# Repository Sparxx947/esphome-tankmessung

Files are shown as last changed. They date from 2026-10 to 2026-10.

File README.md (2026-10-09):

🇬🇧 [English version](README.en.md)

# Tankmessung – pneumatische Füllstandsmessung am Öltank

ESP32 + ESPHome misst den Füllstand des Heizöl-Erdtanks über die **vorhandene pneumatische Messleitung**
und meldet Druck, Füllhöhe und Literinhalt an Home Assistant (Gerät „Öltank“).

> Stand: **09.10.2026**. Am Tank eingebaut und in Betrieb: Messleitung frei, dicht, automatische Messung alle 6 h an.
> Füllstand vorläufig über die Lieferbilanz abgeglichen (Peilstab nicht erreichbar); genauer Abgleich bei der nächsten Lieferung.

> **Nachbauen?** Die Werte in diesem Repo gehören zu *diesem* Tank und *diesem* Sensor:
> - Eigene `secrets.yaml` aus [`firmware/secrets.example.yaml`](firmware/secrets.example.yaml) anlegen (WLAN, API-Schlüssel, Passwort des Fallback-Hotspots).
> - Die Tankgeometrie-Substitutions `tank_radius_dm`, `tank_laenge_dm` und `tank_nenn_l` sowie die Öldichte (`oel_mbar_pro_cm`) an den eigenen Tank anpassen.
> - `roh_null` und `roh_pro_mbar` selbst einmessen (siehe [docs/einmessen.md](docs/einmessen.md)) – die Werte in der Firmware gelten nur für genau diesen HX710B-Sensor.

---

## 1. Kurzbeschreibung

| | |
|---|---|
| **Was** | Füllstand des Heizöltanks (Druck in mbar → Füllhöhe in cm → Inhalt in Litern) |
| **Tank** | Stahl-Erdtank, draußen unterirdisch, **7.000 l**, DIN 6608-D, Baujahr 1967, doppelwandig mit Leckanzeiger. Maße laut DIN-6608-Tabelle (heutige Norm): **Ø 1.600 mm × 3.750 mm** – die Normfassung von 1967 ist nicht gegengeprüft. |
| **Wo** | Heizungskeller, an der Wand neben der alten pneumatischen Anzeige (Skala 0–7.000 l mit Zugpumpe). Abgriff: senkrechtes Kupferstück (6 mm) zwischen Abscheiderbecher und alter Anzeige. |
| **Prinzip** | Wie die alte Anzeige („Vor dem Ablesen pumpen“): Eine Mini-Pumpe drückt Luft in die Messleitung, bis sie am Leitungsende ausperlt. Nach dem Abschalten hält ein Rückschlagventil die Luft in der Leitung; der Restdruck entspricht der Ölsäule über dem Leitungsende. Ein Drucksensor (HX710B, 0–40 kPa) misst ihn – auch **während** des Pumpens, mit Überdruck-Abschaltung. Das Leitungsende sitzt über dem Tankboden; die Höhe darunter wird als einstellbare Korrektur addiert. |
| **Physik** | Heizöl EL ρ ≈ 0,84 kg/l → **1 cm Öl ≈ 0,824 mbar**, voller Tank (160 cm) ≈ **132 mbar**, 1 m Öl ≈ 82 mbar. |
| **Volumen** | Liegender Zylinder (Kreisabschnitt), Böden vernachlässigt, auf 7.000 l skaliert (Formel in [docs/einmessen.md](docs/einmessen.md)). |

Die alte Anzeige bleibt angeschlossen, ist aber **defekt** (zeigt drucklos ~800 l, gepumpt knapp 1.900 l bei tatsächlich ~1.500 l). Ergänzend gibt es das Projekt „Heizung über Optolink“
(zweiter ESP32, `heizung-optolink`, .193) für Brennerstunden und Störmeldungen – nicht Teil dieses Repos.

---

## 2. Status (Stand 09.10.2026)

| Bereich | Status | Datum / Hinweis |
|---|---|---|
| Firmware geflasht, in HA, im ESPHome Builder | ✅ fertig | 06.10.2026 ~20:00 |
| Feste IP in der FRITZ!Box (.194) | ✅ fertig | 06.10.2026 |
| MOSFET-Modul: D4184 als untauglich erkannt, durch CQUANZX Dual-MOSFET ersetzt | ✅ fertig | erkannt 06.10., geliefert 07.10. |
| Gehäuse korrigiert (Stützen, SMA-Lage, Laschen, HX710B-Stützen, Innenhöhe 40) | ✅ fertig | 08.10.2026 |
| Gehäuse gedruckt und bestückt, Bestückungsplan gedruckt | ✅ fertig | 08.10.2026 |
| Erster Pumpentest | ✅ läuft (nach Nachklemmen) | 08.10.2026 15:27 |
| **Einmessen am Tisch** (Wassersäule 10 cm) | ✅ fertig | 08.10.2026 16:25, Gegenprobe 16:27 |
| Funktion + Dichtprobe in der Box (60 s) | ✅ dicht (2 von 3 Läufen, ein Abfall ungeklärt) | 08.10.2026 18:07–18:15 |
| Messing-T 6×4×6 | ✅ geliefert, eingebaut | 09.10.2026 |
| **Messleitung frei?** | ✅ frei | 09.10.2026: Druck bleibt beim Pumpen flach auf der Ölsäule (Luft perlt aus) – Freiblasen war nicht nötig |
| Einbau am Tank, erster Lauf, Dichtprobe | ✅ fertig | 09.10.2026 15:44–16:07 (ein Leck an den neuen Anschlüssen gefunden und abgedichtet) |
| Überdruck-Abschaltung + Leitungsende-Korrektur (Firmware) | ✅ geflasht | 09.10.2026 15:52 / 16:06 – Abschaltung **noch nie ausgelöst**, im Ernstfall ungetestet |
| Abgleich Füllstand | ⚠️ vorläufig | Peilstab nicht erreichbar → Lieferbilanz, Korrektur 6,5 cm (Mindestwert); genau bei der nächsten Lieferung |
| Automatische Messung (alle 6 h) | ✅ an | seit 09.10.2026 16:07 |
| HA-Automationen (Warnung, Prognose) | ❌ offen | noch keine angelegt (geprüft 08.10.: keine Automation/kein Skript nutzt das Gerät) |

---

## 3. Stückliste

Quelle: Projektnotizen und Werkstattbuch. Preise zum Bestellzeitpunkt (Oktober 2026, Amazon.de).
Der erste Warenkorb für die Pneumatik (8 Artikel, 54,62 €) wurde am 04.10.2026 bestellt.

### Elektronik

| Teil | Menge | Bezeichnung / Typ | Bezugsquelle, ASIN, Preis | Status |
|---|---|---|---|---|
| Mikrocontroller | 1 | ESP32-WROOM-32U DevKitC V4, USB-C, mit Antennen-Kit (U.FL→SMA-Pigtail + 2,4-GHz-Antenne), Board `esp32dev`, CP2102 | Amazon B0F6567LB5, 13,99 € je Stück (2 bestellt; das zweite steckt im Optolink-Projekt) | ✅ vorhanden, geflasht |
| Drucksensor | 1 (von 3) | Drucksensor-Modul 0–40 kPa mit HX710B (24 bit), Schlauchstutzen für 2,5-mm-Schlauch | Amazon B0B1TZH7RR, 10,99 € (3 Stück) | ✅ vorhanden, eingebaut |
| Luftpumpe | 1 | Mini-Membranpumpe „M20“, DC 3–3,7 V, 80–120 kPa; abgeflachter N20-Motor, 9,95 mm (flache Seiten) × 38 mm, 2 Stutzen stirnseitig, Lötfahnen hinten | Amazon B0GQ3MWP3R, 6,89 € (nur 2 Bewertungen) | ✅ vorhanden, eingebaut |
| MOSFET-Modul | 1 (von 5) | Dual-MOSFET-Triggermodul 15 A / 400 W („XY-MOS“, 2× AOD4184A parallel, **ohne** Optokoppler), Trigger 3,3–20 V, Last 5–36 V, PWM 0–20 kHz, 35 × 17,2 × 14,2 mm | Amazon CQUANZX B07VRCXGFY, 8,49 € (5 Stück) | ✅ geliefert 07.10., eingebaut |
| Freilaufdiode | 1 | Schottky 1N5819 | Diodensortiment BOJACK B07YK3XMQQ, 10,99 € | ✅ geliefert 07.10., eingebaut |
| ~~MOSFET-Modul D4184~~ | – | DollaTek „D4184 MOSFET-Modul“ (PC817-Optokoppler, Gate aus der Lastspannung) – **Fehlkauf, schaltet an 5 V nicht** | Amazon B07HBVTWMY, 5,99 € (5 Stück) | ⚠️ ungenutzt; stornieren oder behalten: Jens entscheidet |
| Kabel | ca. 8 | Dupont-Jumper F2F/M2F (ELEGOO-Set, 20 cm) | vorhanden (gekauft 2023) | ✅ vorhanden |
| Netzteil | 1 | USB-C-Netzteil **≥ 1 A**, 5 V | in den Notizen nicht festgehalten | ❓ ungeklärt |

### Pneumatik

| Teil | Menge | Bezeichnung / Typ | Bezugsquelle, ASIN, Preis | Status |
|---|---|---|---|---|
| T-Stück Messleitung | 1 | Messing-Schlauchtülle-T **6 × 4 × 6 mm** (6 mm Durchgang, 4 mm Abzweig) | Amazon B0GHMXRYNT, 5,99 € (2 Stück) | ✅ eingebaut 09.10. |
| Silikonschlauch 6 mm innen | 1 m | Silikonschlauch 6 mm ID (auf die durchtrennte 6-mm-Kupferleitung) | Amazon B0CYGQD96H, 5,59 € | bestellt 04.10. (Lieferung nicht ausdrücklich notiert) |
| Schlauchschellen | 10 | Edelstahl-Schlauchschellen 6–12 mm (Leryati) | Amazon B0C24792WR, 4,99 € | bestellt 04.10. (Lieferung nicht ausdrücklich notiert) |
| Aquarium-Set | 1 | 48-teilig: 6 m Silikonschlauch 4 mm, Rückschlagventile, T- und L-Verbinder | Amazon B0C2PYBDGJ, 9,99 € | ✅ vorhanden, in der Box verbaut (Rückschlagventil + T) |
| Silikonschlauch 2,5 mm | 1 m | Silikonschlauch 2,5 mm ID × 4 mm AD – passt auf den Sensorstutzen und stramm in den 4-mm-Aquariumschlauch | Amazon B0CXPW74GZ, 4,19 € | bestellt 04.10. (Lieferung nicht ausdrücklich notiert) |
| Messleitung | – | vorhandene Kupferleitung **6 mm außen** (Jens gemessen 6,1 mm) vom Tank in den Keller | Bestand | ✅ frei (09.10.) |

Fallback, falls das Messing-T wieder ausfällt: Steckverbinder-T 6-4-6 POM (B0GLGCTVRH) oder PA (B0CB8V2NXD).
Ungeprüft, ob Steckverbinder auf 6,1-mm-Kupfer dicht und zugfest halten – vor dem Einbau Zugtest + Druckhaltetest.

### Gehäuse und Kleinteile

| Teil | Menge | Bezeichnung / Typ | Bezugsquelle | Status |
|---|---|---|---|---|
| Filament | ca. 1 Box + Deckel | PETG oder PLA (Raumtemperatur, Wandmontage) | Bestand | ✅ Box gedruckt 08.10. (Material nicht notiert) |
| Kabelbinder | 4 | schmal, passend für Schlitze 3,5 × 1,8 mm (2× Pumpe, 1× MOSFET, 1× Ventil) | Bestand | ✅ (Bestand nicht ausdrücklich notiert) |
| Heißkleber | – | HX710B auf seine 2 Stützen | Bestand | ✅ |
| Wandschrauben + Dübel | 4 | für Laschen Ø 4,5 mm (also Schrauben ≤ 4 mm) | – | ❓ nicht in den Notizen |
| Magnete | 0 | – (die 10 × 3-mm-Magnete gehören zum Optolink-Gehäuse) | – | – |
| Widerstände | 0 | Die Schaltung braucht keine (HX710B-Modul und MOSFET-Modul sind fertig bestückt). | – | – |

### Werkzeug / Hilfsmittel

Messschieber, Multimeter, Lötkolben, 3D-Drucker, Glas mit Wasser + Lineal (Einmessen),
Peilstab für den Domschacht (ggf. mit Wasserfindungspaste) – **am 09.10. nicht erreichbar**, Abgleich daher über die Lieferbilanz.

---

## 4. Pinbelegung und Verdrahtung

Schaltplan: [`plaene/tankmessung-schaltplan.pdf`](plaene/tankmessung-schaltplan.pdf)
(Quelle `plaene/tank_plan.py`, Vorschau `plaene/tank_plan.svg`).
Bestückung der Box: [`plaene/tank-bestueckung.pdf`](plaene/tank-bestueckung.pdf) (Quelle `plaene/tank_bestueckung_plan.py`).

> Der Schaltplan-PDF ist auf Stand **08.10.2026** (85 % PWM, eingemessene Werte). Die SVG-Fassung `tank_plan.svg` zeigt noch den Stand 06.10.; die Verdrahtung ist identisch.

| Von | Nach | Hinweis |
|---|---|---|
| HX710B **VCC** | ESP32 **3V3** | **nicht** an 5 V – sonst 5-V-Pegel an GPIO19 |
| HX710B **GND** | ESP32 GND | gemeinsame Masse |
| HX710B **OUT** | **GPIO19** | ESPHome-Plattform `hx711` (`dout_pin`) |
| HX710B **SCK** | **GPIO18** | `clk_pin`, Gain 128 |
| MOSFET **TRIG/PWM** | **GPIO25** | LEDC-PWM 20 kHz |
| MOSFET **GND** (Steuerseite) | ESP32 GND | |
| MOSFET **VIN+** | ESP32 **5V** | 5 V vom DevKit (aus USB, Netzteil ≥ 1 A) |
| MOSFET **VIN−** | ESP32 GND | |
| MOSFET **OUT+** | Pumpe **+ (rot)** | |
| MOSFET **OUT−** | Pumpe **− (schwarz)** | Modul schaltet **Minus** – Pumpe nur an OUT+/OUT−, nie zwischen VIN− und GND |
| 1N5819 | parallel zur Pumpe | **Strich (Kathode) an OUT+**; mit in die Klemmen |
| Antenne | U.FL am Modul → Pigtail → SMA-Buchse in der Vorderwand | Das WROOM-**32U** hat keine Leiterplattenantenne |

Auf der Modul-Unterseite (XY-MOS, laut Foto 08.10.): OUT+ unten, OUT− oben, VIN rechts. Aufdruck auf dem Modul gilt.

**Schlauchführung:**

```
Tankboden ── Kupfer 6 mm ── Messing-T 6×4×6 ──(6-mm-Silikon + Schellen)── alte Anzeige  (dauerhaft DICHT)
                                 │
                            4-mm-Schlauch
                                 │
                       (rechte Wand der Box)
                                 │
                          Aquarium-T 4 mm ──── HX710B-Stutzen (2,5-mm-Silikon)
                                 │
                       Rückschlagventil  (Pfeil zeigt zum T / zur Leitung)
                                 │
                       Pumpe, blasender Stutzen   (Ansaugstutzen OFFEN lassen)
```

---

## 5. Gehäuse

Quelle: [`gehaeuse/tankmessung-gehaeuse.scad`](gehaeuse/tankmessung-gehaeuse.scad) (OpenSCAD, Variable `TEIL = "box" | "deckel" | "alle"`).

| Datei | Wofür | Maße |
|---|---|---|
| `gehaeuse/tank_box.stl` | Box mit ESP-Fach, Stützen, Kabelbinder-Schlitzen, 4 Wandlaschen | außen 114 × 68 × 42 mm (+ Laschen auf 84 mm Breite), innen 110 × 64 × 40 mm |
| `gehaeuse/tank_deckel.stl` | Steckdeckel mit 3-mm-Rand und Ø-3-mm-Loch über der ESP-Status-LED | 114 × 68 × 4,8 mm |
| `gehaeuse/vorschau_tank.png`, `vorschau_tank_oben.png` | Vorschaubilder | – |

**Material/Druck:** PETG oder PLA, 0,2 mm Schicht, **ohne Stützen**, Boden aufs Bett (Beschriftung „TANKMESSUNG“ ist gespiegelt in den Boden eingelassen).

**Aufteilung (Draufsicht, vorne = Wand mit SMA-Buchse):**

| Bereich | Bauteil | Befestigung |
|---|---|---|
| links (x 2–53) | ESP32 DevKitC, USB-C durch die linke Wand | liegt auf **4 Stützen** (17 mm hoch, je ~4,9 mm breit), Stifte + Dupont nach **unten** |
| Trennsteg x ~53 | 6 mm niedriger Anschlag, Kabel gehen drüber | – |
| vorne, x 62 | SMA-Buchse Ø 6,6 mm, 8 mm über dem Boden | Mutter |
| vorne rechts (x 74–109) | MOSFET-Modul, Klemmen zur Mitte | 1 Kabelbinder |
| Mitte (x ~71–89) | HX710B, Stiftleiste nach vorn/unten, Stutzen nach oben | **Heißkleber** auf 2 Stützen (17 mm) unter den Ohren |
| hinten (x 57–95) | Pumpe längs, Lötfahnen links, Stutzen rechts | 2 Kabelbinder |
| rechts | Rückschlagventil, darunter Aquarium-T | 1 Kabelbinder |
| rechte Wand | Schlauch Ø 6,6 mm unten, optionale Kabeldurchführung Ø 5 mm oben | – |
| Rückwand | 8 Lüftungsschlitze | – |

**Lehren aus dem Gehäusebau** (alle vor dem Druck am 08.10. korrigiert):

- **Stiftleisten laufen über die ganze Platinenlänge** (19 × 2,54 mm). Durchgehende Stirn-Auflagen hätten an beiden Enden auf den Stiften gesessen → 4 Einzelstützen, 3,2 mm vom Längsrand, Mitte 12 mm frei (USB-Lötlaschen).
- **SMA-Mutter traf die Stifte**: Bohrung unter der Platine (x 39,5) kollidierte mit der vorderen Stiftleiste → nach x 62 rechts neben das ESP-Fach.
- **Pumpenlaschen lagen quer** zur Pumpe und das MOSFET-Modul ragte 4 mm über die Wand → Laschen nach Jens' Maßen neu gesetzt, Hüllquader-Kollisionsprüfung.
- **HX710B hat die Stiftleiste nach unten** → steht auf Stützen, Innenhöhe 30 → 40 mm (Platz für Stutzen + Schlauchbogen); Dupont ↔ Stützen 1,1/1,4 mm Luft.
- Allgemein: **vor jedem STL-Export Kollisionen prüfen** (Stifte, Muttern, Stecker), Teile vorher mit dem Messschieber messen.
- Die Lochlinie der HX710B-Ohren ist nur aus einem Foto geschätzt – deshalb Heißkleber statt Schrauben.

Ältere Stände liegen lokal als `*.vor-stuetzen-20261008`, `*.vor-laschen-20261008` (per `.gitignore` nicht im Repo).

---

## 6. Firmware

Datei: [`firmware/tankmessung.yaml`](firmware/tankmessung.yaml) – Stand aus dem ESPHome Builder (09.10.2026).
**Die Fassung im ESPHome Builder ist führend**; Änderungen hier nachziehen.

| Einstellung | Wert |
|---|---|
| Gerätename / Hostname | `tankmessung` / `tankmessung.local` |
| Anzeigename in HA | **Öltank** |
| IP | **192.168.178.194** (feste Zuordnung in der FRITZ!Box per MAC) |
| Board / Framework | `esp32dev`, **esp-idf** |
| Logger | INFO |
| API | verschlüsselt (`!secret tank_api_key`), OTA ohne eigenes Passwort |
| Fallback-Hotspot | `Tank-Fallback` + Captive Portal (Passwort `!secret tank_ap_password`) |

**Substitutions:**

| Name | Wert | Bedeutung |
|---|---|---|
| `roh_null` | `-2788747.0` | HX710B-Rohwert bei 0 mbar (eingemessen 08.10., Sensor warm) |
| `roh_pro_mbar` | `70056.0` | Rohwert-Anstieg je mbar |
| `oel_mbar_pro_cm` | `0.824` | Heizöl EL, ρ ≈ 0,84 |
| `tank_radius_dm` | `8.0` | Ø 1,6 m |
| `tank_laenge_dm` | `37.5` | 3,75 m |
| `tank_nenn_l` | `7000` | Skalierung auf Nennvolumen |

**Pumpe:** `ledc` an GPIO25, 20 kHz, `max_power: 85%` (≈ 4,05 V bei 4,77 V VIN; vorher 70 %).
Die Pumpe ist für 3–3,7 V gebaut und hängt an 5 V – deshalb die Begrenzung.
**Sicherung:** Skript `pumpe_sicherung` schaltet die Pumpe nach **60 s** immer ab, auch bei Handbetrieb.

**Messablauf (Skript `messung`):** Pumpe 100 % (= 85 % PWM) für *Spülzeit* (Standard 30 s). **Während des Pumpens** wird der
HX710B alle 0,5 s gelesen; steigt der Druck über die *Überdruck-Grenze* (Standard 150 mbar), geht die Pumpe sofort aus und die
Messung wird verworfen (`binary_sensor.oltank_uberdruck_abbruch` = an). Füllhöhe und Inhalt werden beim Pumpen **nicht** berechnet.
Sonst: Pumpe aus → *Beruhigungszeit* (Standard 10 s) → **15 Einzelwerte** (alle ~0,25 s) → **Median** als Messwert; die 10–90-%-Spanne der 15 Werte landet als *Messstreuung* in HA. Der Sensor wird **nur** in diesem Skript gelesen
(`update_interval: never`). Der höchste Druck beim Pumpen landet in `sensor.oltank_hochstdruck_beim_pumpen`.

**Füllhöhe** = Druck / 0,824 + *Leitungsende über Boden* (Standard 6,5 cm). Die Messleitung endet über dem Tankboden; Öl darunter
sieht die Messung nicht (Herleitung in [docs/einmessen.md](docs/einmessen.md#3-abgleich-am-tank-nach-dem-einbau)).

> Die Überdruck-Abschaltung ist bisher **nie ausgelöst** worden (die Leitung ist frei) – im Ernstfall ungetestet.

### Entitäten in Home Assistant (17, geprüft 09.10.2026)

| Entität | Typ | Zweck |
|---|---|---|
| `button.oltank_messung_starten` | Knopf | eine Messung auslösen |
| `switch.oltank_automatische_messung` | Schalter (Konfig.) | Messung alle 6 h – **ab Werk AUS** (`RESTORE_DEFAULT_OFF`), hier an seit 09.10. |
| `number.oltank_spulzeit_pumpe` | Zahl 5–60 s | Pumpdauer je Messung (30 s) |
| `number.oltank_beruhigungszeit` | Zahl 2–60 s | Wartezeit vor dem Lesen (10 s; für Dichtproben 60 s) |
| `number.oltank_uberdruck_grenze` | Zahl 50–300 mbar | Überdruck-Abschaltung beim Pumpen (150 mbar) |
| `number.oltank_leitungsende_uber_boden` | Zahl 0–30 cm | Korrektur: Höhe des Leitungsendes über dem Tankboden (6,5 cm) |
| `fan.oltank_pumpe` | Lüfter (Diagnose) | Pumpe von Hand, max. 60 s |
| `sensor.oltank_druck_rohwert` | Diagnose | HX710B-Rohwert (für das Einmessen) |
| `sensor.oltank_druck` | mbar | Druck = Ölsäule |
| `sensor.oltank_fullhohe` | cm | Füllhöhe inkl. Korrektur (begrenzt auf 0–160 cm) |
| `sensor.oltank_inhalt` | L | Inhalt, `device_class: volume_storage` |
| `sensor.oltank_hochstdruck_beim_pumpen` | mbar (Diagnose) | höchster Druck während des Pumpens (freie Leitung ≈ Ölsäule) |
| `binary_sensor.oltank_uberdruck_abbruch` | Problem | an = letzte Messung wegen Überdruck abgebrochen (Leitung zu?) |
| `sensor.oltank_messstreuung` | mbar (Diagnose) | 10–90-%-Spanne der 15 Einzelwerte einer Messung (Chip-Rauschen; gemessen 0,04–0,07 mbar) |
| `sensor.oltank_wlan_signal` | dBm | am Tisch −42 dBm, am Tank −50 bis −61 dBm |
| `sensor.oltank_laufzeit` | s | Uptime |
| `button.oltank_neustart` | Knopf (Diagnose) | ESP neu starten |

### Secrets

`firmware/secrets.example.yaml` ist nur eine Vorlage mit Platzhaltern. Die echten Werte (`wifi_ssid`, `wifi_password`,
`tank_api_key`, `tank_ap_password`) stehen **nur im ESPHome Builder** (und lokal außerhalb des Repos, Rechte 600).
`.gitignore` schließt `secrets.yaml` und `secrets.*.yaml` aus. API-Schlüssel neu erzeugen: `openssl rand -base64 32`.

### Flashen

| Weg | Wann | Wie |
|---|---|---|
| **OTA über den ESPHome Builder** (Normalfall) | jede Änderung | YAML im Builder bearbeiten → *Install* → *Wirelessly*. Gerät ist seit 06.10. ~20:05 im Builder online. |
| **Erstflash per USB** | neues Board / kaputte Firmware | `esphome run tankmessung.yaml --no-logs --device /dev/ttyUSB0` mit **echten** Secrets. Port vorher freigeben (`setfacl -m u:$USER:rw /dev/ttyUSB0`, nach jedem Umstecken neu) oder Gruppe `dialout`. |
| **Notweg bei Abbruch** | „No more data to read“ | Dieses Board kam mit 460800 Baud nicht klar: mit `esptool … --baud 115200` die fertige `firmware.factory.bin` schreiben. |

> ⚠️ **Falle:** Nie einen Prüf-Build mit Dummy-Secrets flashen (am 06.10. beim Schwestergerät passiert: falsches
> Hotspot-Passwort, falscher API-Schlüssel). `esphome upload` **übersetzt nicht neu** und spielt blind den letzten Build auf –
> für echte Firmware immer `esphome run` und auf „Successfully compiled“ achten. Danach per API mit dem echten Schlüssel gegenprüfen.

---

## 7. Anleitungen

| Anleitung | Inhalt |
|---|---|
| [docs/aufbau.md](docs/aufbau.md) | Aufbau und Inbetriebnahme auf dem Tisch |
| [docs/einmessen.md](docs/einmessen.md) | **Einmessen/Kalibrieren** mit Wassersäule, Formeln, Peiltabelle, Abgleich am Tank |
| [docs/einbau.md](docs/einbau.md) | Einbau am Tank, Freiblasen der Messleitung, AwSV, erster Lauf, Dichtprobe |
| [docs/fehlersuche.md](docs/fehlersuche.md) | bekannte Fehlerbilder mit Ursache und Lösung |
| [docs/verlauf.md](docs/verlauf.md) | Projektverlauf 04.–09.10.2026 |

Kurzfassung:

1. **Aufbau** nach `plaene/tank-bestueckung.pdf` (Dupont zuerst stecken, dann ESP auf die Stützen).
2. **Inbetriebnahme:** USB-Netzteil an, Gerät in HA online? „Messung starten“ mit offenem Schlauch → Pumpe läuft, bläst.
3. **Einmessen:** Nullpunkt bei offenem Schlauch (Sensor warm, ≥ 5 min nach Einschalten), dann 10 cm Wassersäule = 9,81 mbar →
   `roh_pro_mbar = (roh_10cm − roh_null) / 9,81`. Gegenprobe muss ~10 mbar ergeben.
4. **Einbau:** Abzweig zur alten Anzeige dauerhaft dicht. Ob die Leitung frei ist, zeigt der erste Lauf (Überdruck-Grenze vorher niedrig, z. B. 50 mbar).
5. **Test:** erster Lauf mit 60 s Beruhigungszeit (Dichtprobe), dann Abgleich (Peilstab oder Lieferbilanz), dann Beruhigungszeit 10 s.
6. Erst dann **„Automatische Messung“** einschalten.

---

## 8. Home-Assistant-Anbindung

- Integration: **ESPHome**, Gerät „Öltank“, 17 Entitäten (Tabelle oben).
- **Genauigkeit (09.10.2026 gemessen):** Chip-Rauschen nur 0,04–0,07 mbar (2–4 l), aber **von Lauf zu Lauf bis ~18 l** (vier Messungen in 5 min: 1.528–1.546 l) – vermutlich wie genau die Luft beim Abschalten ausperlt. Deshalb in HA über die letzten 4 Messungen glätten (statistics-Helfer, Mittelwert, max. 30 h) und Warnschwellen daran hängen.
- Läuft die automatische Messung, misst die Box **nach jedem Neustart sofort** einmal (die Pumpe läuft dann kurz an).
- Es gibt **noch keinen `ha/`-Ordner** und keine Automationen/Skripte, die das Gerät nutzen (Suche in HA am 08.10.2026).
- Geplant (aus den Notizen):
  - **Warnung bei niedrigem Stand:** Vorwarnung 1.500 l, dringend 800 l (Push an die Hausbewohner).
  - **Tankprognose** aus dem Verbrauch; Abgleich mit dem Ölverbrauch aus Brennerstunden × Düsendurchsatz (≤ 2,4 l/h) vom Optolink-Projekt.
  - Plausibilität gegen Liefermengen (Referenz: 3.000 l reichten ~14 Monate).
- Hinweis für Automationen: Die Sensoren ändern sich nur nach einer Messung; bei abgeschalteter Automatik bleibt der letzte Wert stehen.

---

## 9. Offene Punkte / nächste Schritte / Termine

| Punkt | Wer | Termin |
|---|---|---|
| **Genauer Abgleich der Leitungsende-Korrektur:** direkt vor und nach der nächsten Lieferung je eine Messung, Liefermenge vom Lieferschein → Korrektur eindeutig | Jens + Claude | nächste Öllieferung |
| Überdruck-Abschaltung im Ernstfall noch ungetestet | – | beobachten |
| Alte Anzeige defekt (drucklos ~800 l) – behalten oder Abzweig dicht verschließen | Jens | – |
| HA: Warnung 1.500 / 800 l, Prognose | Claude | danach |
| D4184-Fehlkauf stornieren oder behalten | Jens | – |
| Grenzwertgeber mit Lochhülse: jährliche Kontrolle durch Fachbetrieb oder Tausch gegen Schlitzhülse (TÜV-Hinweis 2019 + 2024) | Jens | mit der Tankreinigung |
| Nächste AwSV-Prüfung | Jens | 01/2029 (anmelden ab 11/2028) |

---

## 10. Dateiübersicht

```
esphome-tankmessung/
├── README.md                         diese Datei
├── README.en.md                      diese Datei auf Englisch
├── .gitignore                        schließt Secrets, Build-Ordner, Sicherungsstände aus
├── docs/
│   ├── aufbau.md                     Aufbau + Inbetriebnahme am Tisch
│   ├── einmessen.md                  Kalibrierung, Formeln, Peiltabelle
│   ├── einbau.md                     Einbau am Tank, Freiblasen, AwSV, Dichtprobe
│   ├── fehlersuche.md                Fehlerbilder
│   └── verlauf.md                    Chronik
├── firmware/
│   ├── tankmessung.yaml              ESPHome-Konfiguration (Stand Builder 09.10.2026)
│   └── secrets.example.yaml          Vorlage, keine echten Werte
├── gehaeuse/
│   ├── tankmessung-gehaeuse.scad     OpenSCAD-Quelle (Box + Deckel)
│   ├── tank_box.stl                  Box, Innenhöhe 40 (gedruckt 08.10.)
│   ├── tank_deckel.stl               Steckdeckel
│   ├── vorschau_tank.png             Vorschau
│   └── vorschau_tank_oben.png        Vorschau von oben
└── plaene/
    ├── tankmessung-schaltplan.pdf    Schaltplan + Schlauchführung (Stand 08.10.)
    ├── tank_plan.py                  Erzeuger des Schaltplans (matplotlib)
    ├── tank_plan.svg                 Schaltplan als SVG (Stand 06.10.)
    ├── tank-bestueckung.pdf          Bestückungsplan der Box, Maßstab 2:1 (Stand 08.10.)
    └── tank_bestueckung_plan.py      Erzeuger des Bestückungsplans
```

Die Erzeuger-Skripte schreiben noch auf feste Pfade außerhalb des Repos (`~/esphome/…` bzw. ein Scratchpad) – vor erneutem
Aufruf den Ausgabepfad anpassen.

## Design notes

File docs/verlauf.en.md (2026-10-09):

🇩🇪 [Deutsche Version](verlauf.md)

# Project history

| Date | Event |
|---|---|
| 03/04.10.2026 | Viessmann fault D1 (burner fault) – tank empty, nobody noticed. The old pneumatic gauge nevertheless stood at ~800 l, even after pumping → at the time taken as a silted-up line (disproved on 09.10.: ~800 l is the rest position of the defective gauge). |
| 04.10. | Tank data from the TÜV documents: 7,000 l, DIN 6608-D, built 1967, steel, underground, double wall + leak detector, level-limit sensor (Grenzwertgeber); inspections 2019 and 2024 without defects, next 01/2029. Dimensions Ø 1.6 × 3.75 m from the DIN table. |
| 04.10. | Decision for route B (direct pneumatic measurement on the existing line) with ESP32 + HX710B + mini pump; budget variant with brass barb T instead of compression-fitting parts. Basket ordered. YAML and enclosure (inner height 30) prepared. |
| 05.10. | 1,500 l of heating oil delivered, old gauge showed 1,900 l afterwards. Burner runs again after bleeding. Brass T "could not be shipped". |
| 06.10. ~20:00 | Second ESP32 flashed (115200 baud, 460800 aborted), .194, in HA as `Öltank` (oil tank) (12 entities), static IP, online in the ESPHome Builder. |
| 06.10. evening | D4184 MOSFET module identified as unsuitable for 5 V → CQUANZX dual MOSFET + 1N5819 ordered. Schematic redrawn and printed. |
| 07.10. | Delivery: CQUANZX module, diode assortment. |
| 08.10. ~14:30 | Enclosure corrected before printing: ESP standoffs between the pin rows, SMA next to the ESP compartment, tabs according to measured dimensions (MOSFET 35 × 17.2 × 14.2, pump Ø 9.95 × 38), HX710B on 2 standoffs, inner height 40. Brass T reordered. |
| 08.10. ~14:55 | Box printed. |
| 08.10. 15:21–15:35 | First pump test: pump did not run (terminal contact suspected), runs after re-tightening. Zero point drifted. |
| 08.10. ~16:25 | **Calibrated** with 10 cm water column: `roh_null` −2,788,747, `roh_pro_mbar` 70,056, pump 70 → 85 %. The fault was a leak at the gauge branch. OTA via the Builder. |
| 08.10. 16:27 | Cross-check 10.01/10.02 mbar ✔. |
| 08.10. ~17:40 | Assembly plan created and printed. |
| 08.10. 18:07–18:15 | Box assembled: function ✔, leak test 60 s – one drop (unexplained), two runs tight. Settling time back to 10 s. |
| 08.10. ~18:30 | Question of blowing the line clear yourself; AwSV research: more likely subject to the specialist-company requirement, recommendation: specialist company. |
| 09.10. ~15:44 | **Installation at the tank** (brought forward from 10.10.). Box on the wall, Wi-Fi −61 dBm (later −50 dBm). Brass T fitted, branch to the old gauge sealed. Line not blown clear. |
| 09.10. 15:52 | Firmware: pressure is read **while** pumping every 0.5 s, **overpressure cut-off** (adjustable limit, default 150 mbar), max pressure + abort indicator. Reason: previously the pump ran a fixed 30 s – against a blocked line that would have overloaded the sensor. |
| 09.10. 15:53 | **Run 1** (limit 50 mbar for safety): linear rise ~7 mbar/s, from 15:53:43 a **plateau of 30.95 mbar, flat over 25 s of pumping** = air bubbles out → **line clear**, blowing clear not needed. After the pump stopped: drop 30.9 → 21.4 (10 s) → 19.95 mbar (12 s) = **leak at the new connections**. |
| 09.10. 15:59 | Resealed. **Run 2** (settling 60 s): plateau 31.02–31.05 mbar, after 60 s 29.75 mbar → **practically tight** (~1 mbar drops right after the pump stops = flow component, then almost nothing). |
| 09.10. ~16:00 | **Dipstick not reachable.** Delivery balance instead: 1,500 l into an "empty" tank (burner had stopped), ~35 l consumption → at least ~1,465 l. Measured without correction only 36.1 cm ≈ 1,184 l → **the line end sits above the tank bottom**. |
| 09.10. 16:06 | Firmware: adjustable correction **"line end above bottom"**, default **6.5 cm** = minimum (suction pipe assumed 3 cm above the bottom). |
| 09.10. 16:07 | **Automatic measurement switched on.** Check run: plateau 31.10, after 10 s 30.09 mbar → **43.0 cm ≈ 1,516 l**. |
| 09.10. 19:35 | Firmware: **median of 15 readings** + *measurement spread* sensor. Chip noise 0.04–0.07 mbar; run to run up to ~18 l (19:38–19:43: 1,538.6 / 1,545.7 / 1,529.2 / 1,528.0 l) → smoothing in HA over 4 measurements. |
| 09.10. | **Old gauge defective:** ~800 l without pressure, just under 1,900 l when pumped, with ~1,500 l actually in the tank. |

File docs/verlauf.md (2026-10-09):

🇬🇧 [English version](verlauf.en.md)

# Projektverlauf

| Datum | Ereignis |
|---|---|
| 03./04.10.2026 | Viessmann-Störung D1 (Brennerstörung) – Tank leer, niemand hat es bemerkt. Alte pneumatische Anzeige stand trotzdem bei ~800 l, auch nach dem Pumpen → damals für verschlammte Leitung gehalten (am 09.10. widerlegt: ~800 l ist die Ruhestellung des defekten Manometers). |
| 04.10. | Tankdaten aus den TÜV-Unterlagen: 7.000 l, DIN 6608-D, Baujahr 1967, Stahl, unterirdisch, Doppelwand + Leckanzeiger, Grenzwertgeber; Prüfungen 2019 und 2024 ohne Mängel, nächste 01/2029. Maße Ø 1,6 × 3,75 m aus der DIN-Tabelle. |
| 04.10. | Entscheidung für Weg B (direkte pneumatische Messung an der vorhandenen Leitung) mit ESP32 + HX710B + Mini-Pumpe; Spar-Variante mit Messing-Tüllen-T statt Klemmring-Teilen. Warenkorb bestellt. YAML und Gehäuse (Innenhöhe 30) vorbereitet. |
| 05.10. | 1.500 l Heizöl geliefert, alte Anzeige danach 1.900 l. Brenner läuft nach Entlüften wieder. Messing-T „konnte nicht versandt werden“. |
| 06.10. ~20:00 | Zweiter ESP32 geflasht (115200 Baud, 460800 brach ab), .194, in HA als „Öltank“ (12 Entitäten), feste IP, im ESPHome Builder online. |
| 06.10. abends | D4184-MOSFET-Modul als untauglich für 5 V erkannt → CQUANZX Dual-MOSFET + 1N5819 bestellt. Schaltplan neu gezeichnet und gedruckt. |
| 07.10. | Lieferung: CQUANZX-Modul, Diodensortiment. |
| 08.10. ~14:30 | Gehäuse vor dem Druck korrigiert: ESP-Stützen zwischen den Stiftreihen, SMA neben das ESP-Fach, Laschen nach gemessenen Maßen (MOSFET 35 × 17,2 × 14,2, Pumpe Ø 9,95 × 38), HX710B auf 2 Stützen, Innenhöhe 40. Messing-T nachbestellt. |
| 08.10. ~14:55 | Box gedruckt. |
| 08.10. 15:21–15:35 | Erster Pumpentest: Pumpe lief nicht (Klemmkontakt vermutet), nach Nachklemmen läuft sie. Nullpunkt wanderte. |
| 08.10. ~16:25 | **Eingemessen** mit 10 cm Wassersäule: `roh_null` −2.788.747, `roh_pro_mbar` 70.056, Pumpe 70 → 85 %. Störung war ein Leck am Anzeige-Abzweig. OTA über den Builder. |
| 08.10. 16:27 | Gegenprobe 10,01/10,02 mbar ✔. |
| 08.10. ~17:40 | Bestückungsplan erstellt und gedruckt. |
| 08.10. 18:07–18:15 | Box bestückt: Funktion ✔, Dichtprobe 60 s – ein Abfall (ungeklärt), zwei Läufe dicht. Beruhigungszeit zurück auf 10 s. |
| 08.10. ~18:30 | Frage Freiblasen in Eigenregie; AwSV-Recherche: eher fachbetriebspflichtig, Empfehlung Fachbetrieb. |
| 09.10. ~15:44 | **Einbau am Tank** (vorgezogen vom 10.10.). Box an der Wand, WLAN −61 dBm (später −50 dBm). Messing-T eingesetzt, Abzweig zur alten Anzeige dicht. Leitung nicht freigeblasen. |
| 09.10. 15:52 | Firmware: Druck wird **während** des Pumpens alle 0,5 s gelesen, **Überdruck-Abschaltung** (Grenze einstellbar, Standard 150 mbar), Höchstdruck + Abbruch-Melder. Grund: vorher lief die Pumpe stur 30 s – gegen eine verstopfte Leitung hätte das den Sensor überlastet. |
| 09.10. 15:53 | **Lauf 1** (Grenze 50 mbar zur Sicherheit): linearer Anstieg ~7 mbar/s, ab 15:53:43 **Plateau 30,95 mbar flach über 25 s Pumpen** = Luft perlt aus → **Leitung frei**, Freiblasen unnötig. Nach Pumpenstopp Abfall 30,9 → 21,4 (10 s) → 19,95 mbar (12 s) = **Leck an den neuen Anschlüssen**. |
| 09.10. 15:59 | Neu abgedichtet. **Lauf 2** (Beruhigung 60 s): Plateau 31,02–31,05 mbar, nach 60 s 29,75 mbar → **praktisch dicht** (~1 mbar fällt direkt nach Pumpenstopp = Strömungsanteil, danach fast nichts). |
| 09.10. ~16:00 | **Peilstab nicht erreichbar.** Lieferbilanz statt Peilung: 1.500 l in einen „leeren“ Tank (Brenner stand), ~35 l Verbrauch → mindestens ~1.465 l. Gemessen ohne Korrektur nur 36,1 cm ≈ 1.184 l → **das Leitungsende sitzt über dem Tankboden**. |
| 09.10. 16:06 | Firmware: einstellbare Korrektur **„Leitungsende über Boden“**, Standard **6,5 cm** = Mindestwert (Saugrohr 3 cm über Boden angenommen). |
| 09.10. 16:07 | **Automatische Messung eingeschaltet.** Kontrolllauf: Plateau 31,10, nach 10 s 30,09 mbar → **43,0 cm ≈ 1.516 l**. |
| 09.10. 19:35 | Firmware: **Median aus 15 Einzelwerten** + Sensor *Messstreuung*. Chip-Rauschen 0,04–0,07 mbar; Lauf-zu-Lauf aber bis ~18 l (19:38–19:43: 1.538,6 / 1.545,7 / 1.529,2 / 1.528,0 l) → Glättung in HA über 4 Messungen. |
| 09.10. | **Alte Anzeige defekt:** drucklos ~800 l, gepumpt knapp 1.900 l bei tatsächlich ~1.500 l. |

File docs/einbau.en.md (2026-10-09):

🇩🇪 [Deutsche Version](einbau.md)

# Installation at the tank

**Done on 09.10.2026** (Jens, first run together with Claude). Results in [verlauf.en.md](verlauf.en.md).

## Prerequisite: the measuring line must be clear

With the tank empty (fault D1 on 03/04.10.) the old gauge was stuck at ~800 l, even after pumping. After the delivery
of 1,500 l on 05.10. it showed 1,900 l – from this a silted-up line was concluded.
**Disproved on 09.10.:** the line is clear, the gauge is defective (~800 l without pressure). At the bottom of the clear cup (separator in the measuring line below the gauge) there was something dark/reddish –
possibly oil in the measuring line (unconfirmed).

**Sign of a clear line on the first run:** the pressure rises to the oil column and stays flat **while the pump is running**
(09.10.: 30.95 mbar over 25 s). **Above the overpressure limit = line blocked** → since 09.10. the firmware switches the pump
off itself (sensor limit 40 kPa, pump manages 80–120 kPa). For the first run set the limit low (e.g. 50 mbar).

### AwSV: who may do what

> The AwSV (*Verordnung über Anlagen zum Umgang mit wassergefährdenden Stoffen*, German ordinance on facilities handling
> substances hazardous to water) applies to Germany only; other countries have their own rules.

Research 08.10.2026 (not legal advice):

- The installation is **doubly subject to the specialist-company requirement** under § 45 (1) AwSV: underground (no. 1) and heating-oil consumer installation
  level B (no. 4; 7 m³, WGK 2 – water hazard class 2). Subject to the requirement: erecting, cleaning the inside, **repairing**, decommissioning.
- **Making a silted-up line work again** = "restoring" (§ 2 (29)) = repairing → subject to the requirement, unless under
  § 45 (2) (no direct significance for the safety of the installation). **No** source classifies level indicators.
  → Blowing it clear yourself: **unclear, more likely subject to the requirement**.
- **T-piece in the basement:** unclear, lower risk. Sensor/ESP: electrical exemption under TRwS 791 no. 9.1.
- **Replacing the level-limit sensor (Grenzwertgeber):** definitely subject to the requirement.
- Violation: administrative offence (§ 65 no. 25 AwSV / § 103 WHG); according to the NRW FAQ (2019), if executed technically
  correctly, only a formal deficiency. Insurance terms (water damage) not checked.
- **Recommendation:** a specialist company blows the line clear and fits the T at the same time (ideally together with tank cleaning and replacement of the
  level-limit sensor with perforated sleeve). Otherwise a written enquiry to the responsible lower water authority (untere Wasserbehörde).

### If it is blown clear yourself after all (advice from 08.10., decision lies with Jens)

1. **Heating off** and leave it off for 2–3 h afterwards – the end of the line sits in the bottom sludge; stirring it up otherwise leads to a burner fault (filter).
2. **Unscrew** the old gauge and the cup.
3. First use a **bicycle or ball pump** on the 6 mm copper.
4. Compressor only with a **pressure reducer ≤ ~0.5 bar**, in 1–2 s bursts.
5. Someone listens at the manhole/vent: **bubbling = clear**.
6. Afterwards keep an eye on the oil filter at the burner.

## Procedure

1. **Brass T 6×4×6** into the copper measuring line between the cup and the old gauge: cut the vertical copper section
   in the middle, 6 mm silicone hose onto both ends and the barbs, hose clamps. Operating pressure max. ~0.2 bar.
   (Note: silicone swells in mineral oil – fine as long as there is only air/vapour in the line; with oil better use PU/PA hose.)
2. Connect the **branch to the old gauge permanently sealed**. No check valve as a plug – it leaks (test 08.10.).
3. **Box on the wall** (4 tabs, Ø 4.5 mm), 4 mm hose from the T branch into the right wall of the box, USB power supply ≥ 1 A.
4. Wait ≥ 5 min (sensor warm).
5. **First run** with caution: set `number.oltank_uberdruck_grenze` (overpressure limit) to **50 mbar**, `Messung starten`, watch the
   pressure curve in HA (`sensor.oltank_druck` is reported every 0.5 s while pumping). Flat plateau = clear; abort = line blocked or
   high flow resistance. Afterwards set the limit back to 150 mbar.
6. **Leak test:** set `number.oltank_beruhigungszeit` (settling time) to **60 s**, `Messung starten` ("Start measurement"). The pressure after 60 s must match the one after 10 s.
   On the bench: 10.07 → 10.07 mbar and 10.76 / 10.74 mbar = tight. At the tank (09.10.): first run **leaking**
   (30.9 → 21.4 mbar in 10 s), after resealing 31.0 → 29.75 mbar in 60 s = tight.
7. **Comparison**: dipstick in the manhole – or, if it cannot be reached (09.10.), via the **delivery balance**
   (see [einmessen.en.md](einmessen.en.md#3-comparison-at-the-tank-after-installation)) and set `number.oltank_leitungsende_uber_boden`.
8. Settling time **back to 10 s**.
9. Only now **switch on** `switch.oltank_automatische_messung` (automatic measurement; measurement every 6 h).

## Do not touch

- **AFRISO leak detector** above the gauge (tank is double-walled) – the leak lamp was off.
- The old gauge stays connected (read after pumping with the black knob) but reads wrong (gauge defective, ~800 l without pressure).

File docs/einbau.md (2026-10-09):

🇬🇧 [English version](einbau.en.md)

# Einbau am Tank

**Erledigt am 09.10.2026** (Jens, erster Lauf zusammen mit Claude). Ergebnisse in [verlauf.md](verlauf.md).

## Voraussetzung: Die Messleitung muss frei sein

Die alte Anzeige stand bei leerem Tank (Störung D1 am 03./04.10.) fest bei ~800 l, auch nach dem Pumpen. Nach der Lieferung
von 1.500 l am 05.10. zeigte sie 1.900 l – daraus wurde auf eine verschlammte Leitung geschlossen.
**Am 09.10. widerlegt:** Die Leitung ist frei, das Manometer ist defekt (drucklos ~800 l). Am Boden des Klarsichtbechers (Abscheider in der Messleitung unter der Anzeige) lag etwas Dunkles/Rötliches –
möglicherweise Öl in der Messleitung (unbelegt).

**Frei-Kennzeichen beim ersten Lauf:** Der Druck steigt bis zur Ölsäule und bleibt **bei laufender Pumpe** flach stehen
(09.10.: 30,95 mbar über 25 s). **Über der Überdruck-Grenze = Leitung zu** → die Firmware schaltet die Pumpe seit 09.10.
selbst ab (Sensorgrenze 40 kPa, Pumpe schafft 80–120 kPa). Für den ersten Lauf die Grenze niedrig setzen (z. B. 50 mbar).

### AwSV: wer darf was

Recherche 08.10.2026 (keine Rechtsberatung):

- Die Anlage ist **doppelt fachbetriebspflichtig** nach § 45 Abs. 1 AwSV: unterirdisch (Nr. 1) und Heizölverbraucheranlage
  Stufe B (Nr. 4; 7 m³, WGK 2). Pflichtig sind Errichten, innen Reinigen, **Instandsetzen**, Stilllegen.
- **Verschlammte Leitung wieder gängig machen** = „Wiederherstellen“ (§ 2 Abs. 29) = Instandsetzen → pflichtig, außer nach
  § 45 Abs. 2 (keine unmittelbare Bedeutung für die Anlagensicherheit). Für Füllstandsanzeiger ordnet das **keine** Quelle ein.
  → Freiblasen selbst: **unklar, eher pflichtig**.
- **T-Stück im Keller:** unklar, geringeres Risiko. Sensor/ESP: Elektro-Ausnahme nach TRwS 791 Nr. 9.1.
- **Grenzwertgeber-Tausch:** sicher pflichtig.
- Verstoß: Ordnungswidrigkeit (§ 65 Nr. 25 AwSV / § 103 WHG); laut NRW-Zweifelsfragen (2019) bei technisch einwandfreier
  Ausführung nur Ordnungsmangel. Versicherungsbedingungen (Gewässerschaden) ungeprüft.
- **Empfehlung:** Fachbetrieb bläst frei und setzt das T gleich mit (am besten zusammen mit Tankreinigung und Tausch des
  Grenzwertgebers mit Lochhülse). Sonst schriftliche Anfrage an die zuständige untere Wasserbehörde.

### Falls doch selbst freigeblasen wird (Rat vom 08.10., Entscheidung bei Jens)

1. **Heizung aus** und danach 2–3 h aus lassen – das Leitungsende liegt im Bodenschlamm, Aufwirbeln führt sonst zu Brennerstörung (Filter).
2. Alte Anzeige und Becher **abschrauben**.
3. Zuerst mit einer **Fahrrad- oder Ballpumpe** auf das 6-mm-Kupfer.
4. Kompressor nur mit **Druckminderer ≤ ~0,5 bar**, in 1–2-s-Stößen.
5. Jemand horcht am Domschacht/an der Entlüftung: **Blubbern = frei**.
6. Danach den Ölfilter am Brenner beobachten.

## Ablauf

1. **Messing-T 6×4×6** in die Kupfer-Messleitung zwischen Becher und alter Anzeige: senkrechtes Kupferstück mittig
   durchtrennen, 6-mm-Silikonschlauch auf beide Enden und die Tüllen, Schlauchschellen. Betriebsdruck max. ~0,2 bar.
   (Hinweis: Silikon quillt in Mineralöl – in Ordnung, solange nur Luft/Dunst in der Leitung ist; bei Öl lieber PU/PA-Schlauch.)
2. **Abzweig zur alten Anzeige dauerhaft dicht** anschließen. Kein Rückschlagventil als Verschluss – das leckt (Test 08.10.).
3. **Box an die Wand** (4 Laschen, Ø 4,5 mm), 4-mm-Schlauch vom T-Abzweig in die rechte Wand der Box, USB-Netzteil ≥ 1 A.
4. ≥ 5 min warten (Sensor warm).
5. **Erster Lauf** mit Vorsicht: `number.oltank_uberdruck_grenze` auf **50 mbar**, „Messung starten“, Druckverlauf in HA ansehen
   (`sensor.oltank_druck` wird beim Pumpen alle 0,5 s gemeldet). Flaches Plateau = frei; Abbruch = Leitung zu oder hoher
   Strömungswiderstand. Danach Grenze zurück auf 150 mbar.
6. **Dichtprobe:** `number.oltank_beruhigungszeit` auf **60 s**, „Messung starten“. Der Druck nach 60 s muss dem nach 10 s
   entsprechen. Am Tisch: 10,07 → 10,07 mbar und 10,76 / 10,74 mbar = dicht. Am Tank (09.10.): erster Lauf **undicht**
   (30,9 → 21,4 mbar in 10 s), nach Neuabdichten 31,0 → 29,75 mbar in 60 s = dicht.
7. **Abgleich**: Peilstab im Domschacht – oder, wenn er nicht erreichbar ist (09.10.), über die **Lieferbilanz**
   (siehe [einmessen.md](einmessen.md#3-abgleich-am-tank-nach-dem-einbau)) und `number.oltank_leitungsende_uber_boden` setzen.
8. Beruhigungszeit **zurück auf 10 s**.
9. Erst jetzt `switch.oltank_automatische_messung` **einschalten** (Messung alle 6 h).

## Nicht anfassen

- **AFRISO-Leckanzeiger** über der Anzeige (Tank doppelwandig) – Leck-Lampe war aus.
- Die alte Anzeige bleibt angeschlossen (Ablesen nach dem Pumpen mit dem schwarzen Knopf), zeigt aber falsch (Manometer defekt, drucklos ~800 l).

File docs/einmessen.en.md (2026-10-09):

🇩🇪 [Deutsche Version](einmessen.md)

# Calibration

The chain in the firmware:

```
Rohwert (HX710B, 24 bit)  →  Druck p [mbar]  →  Füllhöhe h [cm]  →  Inhalt V [l]
```

(Rohwert = raw value, Druck = pressure, Füllhöhe = fill height, Inhalt = contents.)

## 1. Formulas

| Step | Formula | Constant |
|---|---|---|
| Raw value → pressure | `p = (roh − roh_null) / roh_pro_mbar` | `roh_null = −2.788.747`, `roh_pro_mbar = 70.056` |
| Pressure → fill height | `h = p / 0,824` (clamped to 0 … 160 cm) | Heating oil EL ρ ≈ 0.84 kg/l: 0.84 × 9.81 × 0.01 / 100 ≈ 0.824 mbar/cm |
| Fill height → contents | Circular segment `A = r²·acos((r−h)/r) − (r−h)·√(2rh − h²)` with h in dm, `V = A · L · 7000 / (π·r²·L)` | r = 8 dm, L = 37.5 dm (dished ends neglected, scaled to 7,000 l) |
| Water for calibration | 10 cm water column = **9.81 mbar** | ρ water = 1.0 |

(The constants in the formula column use German number formatting: `−2.788.747` = −2,788,747; `0,824` = 0.824.)

## 2. Calibration on the bench (as done on 08.10.2026)

Required: glass of water, ruler, the box with hose connected, HA entity `sensor.oltank_druck_rohwert` (pressure raw value).

1. **Warm-up:** switch on the device and wait **at least 5 minutes**. Measured: the zero point moved by ~38,500 units in the first
   minutes (≈ 0.55 mbar ≈ 7 mm oil), stable afterwards (16:16 → 16:21 Δ ~300). Noise ~100–300.
2. **Seal the gauge branch:** on the bench, the T had a branch "to the old gauge". A check valve used as a plug leaks
   already at ~10 mbar – that was the actual fault on 08.10. Hold the branch shut or seal it firmly.
3. **Zero point:** hose end open to the air, `Messung starten` ("Start measurement"), note the raw value (2 readings) → `roh_null`.
   - 08.10.: **−2,788,747** (warm).
4. **Slope:** hose end vertically **10 cm below the water surface** (measured from the hose mouth), `Messung starten` ("Start measurement"),
   it must bubble; note the raw value.
   - 08.10.: **−2,101,492**.
5. Calculate:
   ```
   roh_pro_mbar = (roh_10cm − roh_null) / 9,81
                = (−2.101.492 − (−2.788.747)) / 9,81
                = 687.255 / 9,81 ≈ 70.056
   ```
6. Enter the values into the `substitutions` of the YAML in the **ESPHome Builder** → OTA. Mirror the change in the local `firmware/tankmessung.yaml`.
7. **Cross-check:** 10 cm of water again → target 9.81 mbar.
   - 08.10. 16:27: **10.01 / 10.02 mbar** (+2 % ≈ 2 mm immersion depth), fill height 12.1 cm oil equivalent, contents 243 l. ✔

Tolerance: the immersion depth by hand varies by a few millimetres (later runs 10.07 … 10.76 mbar). For the tank,
1 mbar ≈ 1.2 cm of oil; in the lower range that is 20–45 l depending on the height.

## 3. Comparison at the tank (after installation)

The bench calibration only calibrates the sensor. At the tank, further factors come in: position of the line end above the tank bottom,
actual tank dimensions and the oil density. Therefore check against an independent measurement:

1. **Dipstick in the manhole** (possibly with water-finding paste, to detect water/sludge at the bottom).
2. Expectation after the delivery of 05.10. (1,500 l into an "empty" tank, old gauge showed 1,900 l afterwards):

   | Contents | Fill height | Pressure (calculated) |
   |---|---|---|
   | 1,500 l | 42.7 cm | 35.2 mbar |
   | 1,700 l | 46.7 cm | 38.5 mbar |
   | 1,900 l | 50.6 cm | 41.7 mbar |

   Since then the burner has been running again – so the current level is somewhat lower.
   **Resolved on 09.10.:** the 1,900 l were wrong – the old gauge is defective (~800 l without pressure).
3. If the dipstick reading differs:
   - **constant offset in cm** → line end does not sit on the bottom, or sludge; correction via
     `number.oltank_leitungsende_uber_boden` (in the firmware since 09.10., added to the fill height).
   - **proportional deviation** → oil density/tank dimensions; adjust `oel_mbar_pro_cm`.
4. Later, additionally cross-check with every **delivered quantity** (increase in litres before/after the delivery).

### Comparison without a dipstick: delivery balance (09.10.2026)

The dipstick could not be reached. Instead:

- 05.10.: **1,500 l** into an "empty" tank (the burner got no more oil = level at the end of the suction pipe).
- Consumption until 09.10. ~35 l (estimated, ~7 l/day in October) → now **at least ~1,465 l** + the remainder below the suction pipe.
- Measured **without** correction: 30.95–31.1 mbar while pumping, ≈ 30 mbar after 10 s → 36.1 cm ≈ **1,184 l** – less than
  the delivery alone. → The line end sits **above the tank bottom**.

The remainder below the suction pipe stays unknown. Depending on it:

| Suction pipe ends … above bottom | Remainder before delivery | Contents now | Line end above bottom |
|---|---|---|---|
| 3 cm | 30 l | ≈ 1,495 l | **6.5 cm** (set) |
| 5 cm | 65 l | ≈ 1,530 l | 7.2 cm |
| 10 cm | 182 l | ≈ 1,647 l | 9.6 cm |
| 15 cm | 331 l | ≈ 1,796 l | 12.5 cm |
| 20 cm | 505 l | ≈ 1,970 l | 15.8 cm |

The **minimum of 6.5 cm** is set: contents are shown rather too low – the safe side for warnings.
Check run 09.10. 16:07: **43.0 cm ≈ 1,516 l**.

**Exact comparison at the next delivery:** one measurement directly before and one directly after, quantity from the delivery
note. Because the tank is round, each centimetre corresponds to a different number of litres depending on the height – two
heights plus the known litre difference give the correction unambiguously.

## 4. Dipstick table (from the firmware formula)

Calculated with r = 8 dm, L = 37.5 dm, scaled to 7,000 l, 0.824 mbar/cm. The expected raw value applies to the
calibration of 08.10. Pressure and raw value apply **without** the line-end correction; with the correction, a pressure
belongs to the fill height "table height + correction".

| Fill height | Contents | Pressure | Raw value (expected) |
|---|---|---|---|
| 10 cm | 182 l | 8.2 mbar | −2,211,000 |
| 20 cm | 505 l | 16.5 mbar | −1,634,000 |
| 28 cm | 823 l | 23.1 mbar | −1,172,000 |
| 30 cm | 909 l | 24.7 mbar | −1,057,000 |
| 40 cm | 1,369 l | 33.0 mbar | −480,000 |
| 50 cm | 1,869 l | 41.2 mbar | +98,000 |
| 60 cm | 2,398 l | 49.4 mbar | +675,000 |
| 70 cm | 2,944 l | 57.7 mbar | +1,252,000 |
| 80 cm | 3,500 l | 65.9 mbar | +1,829,000 |
| 100 cm | 4,602 l | 82.4 mbar | +2,984,000 |
| 120 cm | 5,631 l | 98.9 mbar | +4,138,000 |
| 140 cm | 6,495 l | 115.4 mbar | +5,293,000 |
| 160 cm | 7,000 l | 131.8 mbar | +6,447,000 |

Warning thresholds (planned): 1,500 l ≈ 42.7 cm, 800 l ≈ 27.5 cm.

> Note (calculated, not verified on the device): the HX710B delivers 24-bit values up to +8,388,607. With this calibration
> that would be reached at around **160 mbar**. A full tank (132 mbar) still fits; values above that are not a fill level,
> but pump pressure in a blocked line.

## 5. Settings after calibration

| Entity | Normal operation | Leak test |
|---|---|---|
| `number.oltank_spulzeit_pumpe` (pump flush time) | 30 s | 30 s |
| `number.oltank_beruhigungszeit` (settling time) | **10 s** | 60 s |
| `number.oltank_uberdruck_grenze` (overpressure limit) | 150 mbar | 150 mbar (first run on a new line: 50 mbar) |
| `number.oltank_leitungsende_uber_boden` (line end above bottom) | 6.5 cm (provisional, see above) | – |
| `switch.oltank_automatische_messung` (automatic measurement) | **on** only after the comparison at the tank (on since 09.10.) | off |

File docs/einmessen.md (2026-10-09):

🇬🇧 [English version](einmessen.en.md)

# Einmessen / Kalibrieren

Die Kette in der Firmware:

```
Rohwert (HX710B, 24 bit)  →  Druck p [mbar]  →  Füllhöhe h [cm]  →  Inhalt V [l]
```

## 1. Formeln

| Schritt | Formel | Konstante |
|---|---|---|
| Rohwert → Druck | `p = (roh − roh_null) / roh_pro_mbar` | `roh_null = −2.788.747`, `roh_pro_mbar = 70.056` |
| Druck → Füllhöhe | `h = p / 0,824` (begrenzt auf 0 … 160 cm) | Heizöl EL ρ ≈ 0,84 kg/l: 0,84 × 9,81 × 0,01 / 100 ≈ 0,824 mbar/cm |
| Füllhöhe → Inhalt | Kreisabschnitt `A = r²·acos((r−h)/r) − (r−h)·√(2rh − h²)` mit h in dm, `V = A · L · 7000 / (π·r²·L)` | r = 8 dm, L = 37,5 dm (Böden vernachlässigt, auf 7.000 l skaliert) |
| Wasser zum Einmessen | 10 cm Wassersäule = **9,81 mbar** | ρ Wasser = 1,0 |

## 2. Einmessen am Tisch (so am 08.10.2026 gemacht)

Benötigt: Glas mit Wasser, Lineal, die Box mit angeschlossenem Schlauch, HA-Entität `sensor.oltank_druck_rohwert`.

1. **Aufwärmen:** Gerät einschalten und **mindestens 5 Minuten** warten. Gemessen: Der Nullpunkt wanderte in den ersten
   Minuten um ~38.500 Einheiten (≈ 0,55 mbar ≈ 7 mm Öl), danach stabil (16:16 → 16:21 Δ ~300). Rauschen ~100–300.
2. **Anzeige-Abzweig dicht machen:** Am Tisch hing am T ein Ast „zur alten Anzeige“. Ein Rückschlagventil als Stopfen leckt
   schon bei ~10 mbar – das war am 08.10. die eigentliche Störung. Ast zuhalten oder fest verschließen.
3. **Nullpunkt:** Schlauchende offen an der Luft, „Messung starten“, Rohwert notieren (2 Lesungen) → `roh_null`.
   - 08.10.: **−2.788.747** (warm).
4. **Steigung:** Schlauchende senkrecht **10 cm unter die Wasseroberfläche** (gemessen ab Schlauchmündung), „Messung starten“,
   es muss perlen; Rohwert notieren.
   - 08.10.: **−2.101.492**.
5. Rechnen:
   ```
   roh_pro_mbar = (roh_10cm − roh_null) / 9,81
                = (−2.101.492 − (−2.788.747)) / 9,81
                = 687.255 / 9,81 ≈ 70.056
   ```
6. Werte in die `substitutions` der YAML im **ESPHome Builder** eintragen → OTA. Lokale `firmware/tankmessung.yaml` nachziehen.
7. **Gegenprobe:** wieder 10 cm Wasser → Soll 9,81 mbar.
   - 08.10. 16:27: **10,01 / 10,02 mbar** (+2 % ≈ 2 mm Eintauchtiefe), Füllhöhe 12,1 cm Öl-Äquivalent, Inhalt 243 l. ✔

Toleranz: Die Eintauchtiefe von Hand schwankt um einige Millimeter (spätere Läufe 10,07 … 10,76 mbar). Für den Tank
bedeutet 1 mbar ≈ 1,2 cm Öl; im unteren Bereich sind das je nach Höhe 20–45 l.

## 3. Abgleich am Tank (nach dem Einbau)

Das Tisch-Einmessen kalibriert nur den Sensor. Am Tank kommen hinzu: Lage des Leitungsendes über dem Tankboden,
tatsächliche Tankmaße und die Öldichte. Deshalb gegen eine unabhängige Messung prüfen:

1. **Peilstab im Domschacht** (ggf. mit Wasserfindungspaste, um Wasser/Schlamm am Boden zu erkennen).
2. Erwartung nach der Lieferung vom 05.10. (1.500 l in einen „leeren“ Tank, alte Anzeige danach 1.900 l):

   | Inhalt | Füllhöhe | Druck (rechnerisch) |
   |---|---|---|
   | 1.500 l | 42,7 cm | 35,2 mbar |
   | 1.700 l | 46,7 cm | 38,5 mbar |
   | 1.900 l | 50,6 cm | 41,7 mbar |

   Seitdem läuft der Brenner wieder – der aktuelle Stand liegt also etwas darunter.
   **Geklärt am 09.10.:** Die 1.900 l waren falsch – das alte Manometer ist defekt (drucklos ~800 l).
3. Weicht die Peilung ab:
   - **konstanter Versatz in cm** → Leitungsende sitzt nicht am Boden bzw. Schlamm; Korrektur über
     `number.oltank_leitungsende_uber_boden` (seit 09.10. in der Firmware, wird zur Füllhöhe addiert).
   - **proportionale Abweichung** → Öldichte/Tankmaße; `oel_mbar_pro_cm` anpassen.
4. Später zusätzlich mit jeder **Liefermenge** gegenprüfen (Zunahme in Litern vor/nach der Lieferung).

### Abgleich ohne Peilstab: Lieferbilanz (09.10.2026)

Der Peilstab war nicht erreichbar. Stattdessen:

- 05.10.: **1.500 l** in einen „leeren“ Tank (der Brenner bekam kein Öl mehr = Spiegel am Ende des Saugrohrs).
- Verbrauch bis 09.10. ~35 l (geschätzt, ~7 l/Tag im Oktober) → jetzt **mindestens ~1.465 l** + Rest unter dem Saugrohr.
- Gemessen **ohne** Korrektur: 30,95–31,1 mbar beim Pumpen, nach 10 s Ruhe ≈ 30 mbar → 36,1 cm ≈ **1.184 l** – weniger als
  allein die Lieferung. → Das Leitungsende sitzt **über dem Tankboden**.

Unbekannt bleibt der Rest unter dem Saugrohr. Abhängig davon:

| Saugrohr endet … über Boden | Rest vor Lieferung | Inhalt jetzt | Leitungsende über Boden |
|---|---|---|---|
| 3 cm | 30 l | ≈ 1.495 l | **6,5 cm** (eingestellt) |
| 5 cm | 65 l | ≈ 1.530 l | 7,2 cm |
| 10 cm | 182 l | ≈ 1.647 l | 9,6 cm |
| 15 cm | 331 l | ≈ 1.796 l | 12,5 cm |
| 20 cm | 505 l | ≈ 1.970 l | 15,8 cm |

Eingestellt ist der **Mindestwert 6,5 cm**: Der Inhalt wird eher zu niedrig angezeigt – für Warnungen die sichere Seite.
Kontrolllauf 09.10. 16:07: **43,0 cm ≈ 1.516 l**.

**Genauer Abgleich bei der nächsten Lieferung:** direkt davor und direkt danach je eine Messung, Liefermenge vom Lieferschein.
Weil der Tank rund ist, entspricht jeder Zentimeter je nach Höhe unterschiedlich vielen Litern – aus zwei Höhen und der
bekannten Literdifferenz ergibt sich die Korrektur eindeutig.

## 4. Peiltabelle (aus der Firmware-Formel)

Rechnerisch mit r = 8 dm, L = 37,5 dm, skaliert auf 7.000 l, 0,824 mbar/cm. Der erwartete Rohwert gilt für die
Einmessung vom 08.10. Druck und Rohwert gelten **ohne** Leitungsende-Korrektur; mit Korrektur gehört ein Druck zur Füllhöhe
„Tabellenhöhe + Korrektur“.

| Füllhöhe | Inhalt | Druck | Rohwert (erwartet) |
|---|---|---|---|
| 10 cm | 182 l | 8,2 mbar | −2.211.000 |
| 20 cm | 505 l | 16,5 mbar | −1.634.000 |
| 28 cm | 823 l | 23,1 mbar | −1.172.000 |
| 30 cm | 909 l | 24,7 mbar | −1.057.000 |
| 40 cm | 1.369 l | 33,0 mbar | −480.000 |
| 50 cm | 1.869 l | 41,2 mbar | +98.000 |
| 60 cm | 2.398 l | 49,4 mbar | +675.000 |
| 70 cm | 2.944 l | 57,7 mbar | +1.252.000 |
| 80 cm | 3.500 l | 65,9 mbar | +1.829.000 |
| 100 cm | 4.602 l | 82,4 mbar | +2.984.000 |
| 120 cm | 5.631 l | 98,9 mbar | +4.138.000 |
| 140 cm | 6.495 l | 115,4 mbar | +5.293.000 |
| 160 cm | 7.000 l | 131,8 mbar | +6.447.000 |

Warnschwellen (geplant): 1.500 l ≈ 42,7 cm, 800 l ≈ 27,5 cm.

> Hinweis (rechnerisch, nicht am Gerät geprüft): Der HX710B liefert 24-bit-Werte bis +8.388.607. Mit dieser Einmessung
> wäre das bei rund **160 mbar** erreicht. Ein voller Tank (132 mbar) passt noch hinein; Werte darüber sind kein Füllstand,
> sondern Pumpendruck in einer verstopften Leitung.

## 5. Einstellungen nach dem Einmessen

| Entität | Normalbetrieb | Dichtprobe |
|---|---|---|
| `number.oltank_spulzeit_pumpe` | 30 s | 30 s |
| `number.oltank_beruhigungszeit` | **10 s** | 60 s |
| `number.oltank_uberdruck_grenze` | 150 mbar | 150 mbar (erster Lauf an neuer Leitung: 50 mbar) |
| `number.oltank_leitungsende_uber_boden` | 6,5 cm (vorläufig, siehe oben) | – |
| `switch.oltank_automatische_messung` | erst nach dem Abgleich am Tank **an** (an seit 09.10.) | aus |

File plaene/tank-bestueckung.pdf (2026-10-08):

# Tankmessung Bestückung der Box (Draufsicht, Deckel ab, Maßstab 2:1)

tank_box.stl Stand 08.10.2026 · Innen 110 × 64 × 40 mm · rote Punktlinien = Kabelbinder durch die Bodenschlitze

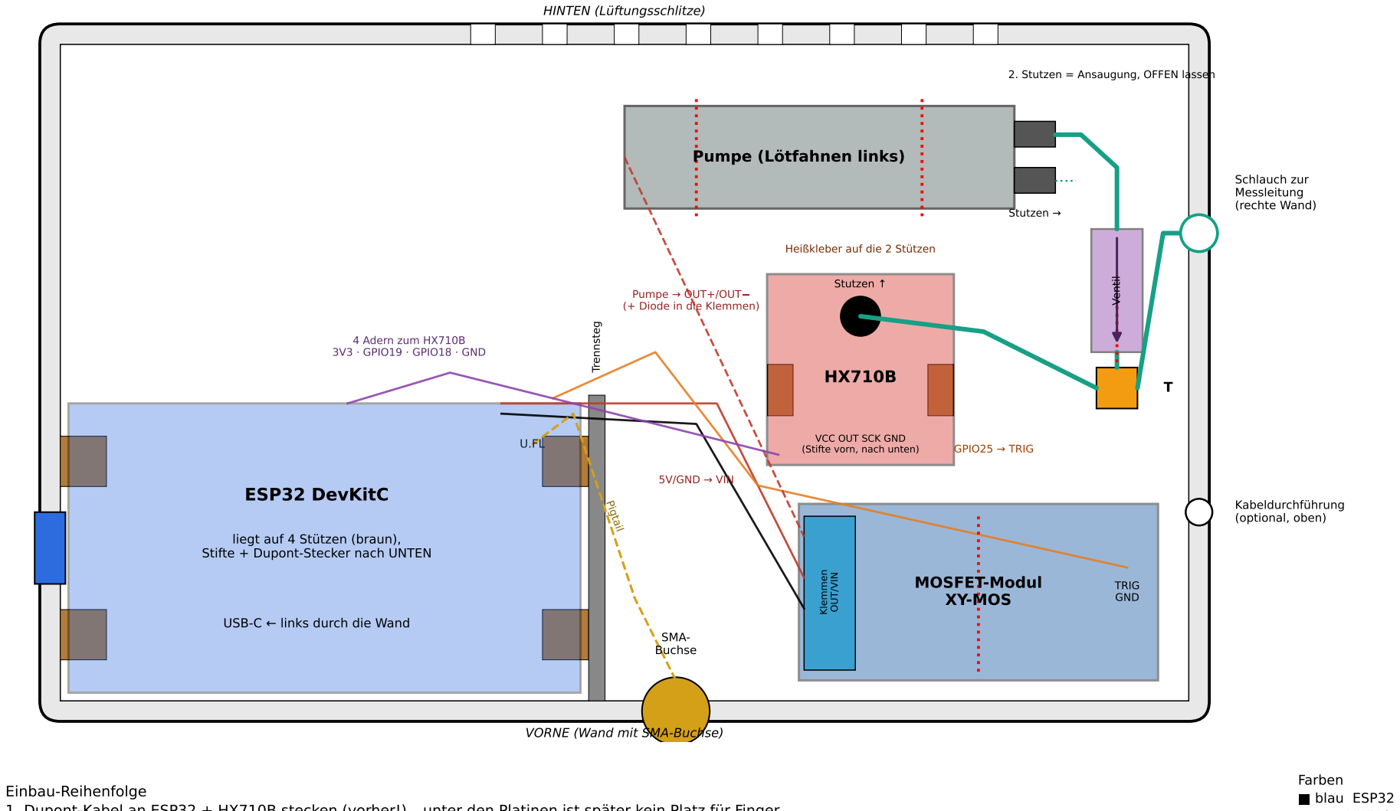
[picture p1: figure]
VORNE (Wand mit SMA-Buchse); HINTEN (Lüftungsschlitze); ESP32 DevKitC; liegt auf 4 Stützen (braun), Stifte + Dupont-Stecker nach UNTEN; USB-C; links durch die Wand; Trennsteg; SMA- Buchse; Pigtail; MOSFET-Modul XY-MOS; Klemmen; OUT/VIN; TRIG GND; VCC OUT SCK GND (Stifte vorn, nach unten); Stutzen; Heißkleber auf die 2 Stützen; Pumpe (Lötfahnen links); Ventil; Schlauch zur Messleitung (rechte Wand); 2. Stutzen = Ansaugung, OFFEN lassen; Kabeldurchführung (optional, oben); 4 Adern zum HX710B 3V3 · GPIO19 · GPIO18 · GND; 5V/GND; VIN; Pumpe; OUT+/OUT; (+ Diode in die Klemmen); GPIO25; TRIG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

1. Dupont-Kabel an ESP32 + HX710B stecken (vorher!) unter den Platinen ist später kein Platz für Finger.
2. ESP32 auf die 4 Stützen legen, USB-C links in die Wandöffnung. Pigtail an U.FL, SMA-Buchse in die vordere Wand rechts neben dem Trennsteg.
3. HX710B mit Heißkleber auf seine 2 Stützen, Stiftleiste nach VORN, Stutzen zeigt nach oben.
4. MOSFET-Modul vorn rechts mit 1 Kabelbinder, Klemmen zur Mitte (links). Diode 1N5819: Strich an OUT+.
5. Pumpe hinten mit 2 Kabelbindern, Stutzen nach rechts. Blasender Stutzen Ventil (Pfeil zum T), Ansaugstutzen offen.
6. Ventil rechts mit 1 Kabelbinder, darunter das T: ein Abgang zum HX710B-Stutzen, einer durch die rechte Wand zur Messleitung.
7. Kabel aufräumen, Deckel drauf. Prüfen: Messung starten am Schlauchende perlt es / bläst es.

rot HX710B
dunkelblau MOSFET
grau Pumpe
lila Rückschlagventil
orange T-Stück
braun Stützen
grün Schläuche
rot Kabelbinder

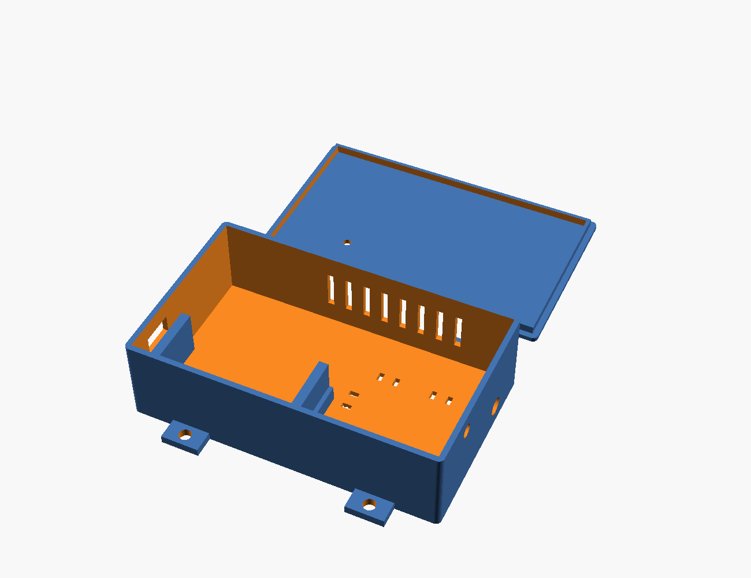
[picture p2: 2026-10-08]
gehaeuse/vorschau_tank.png

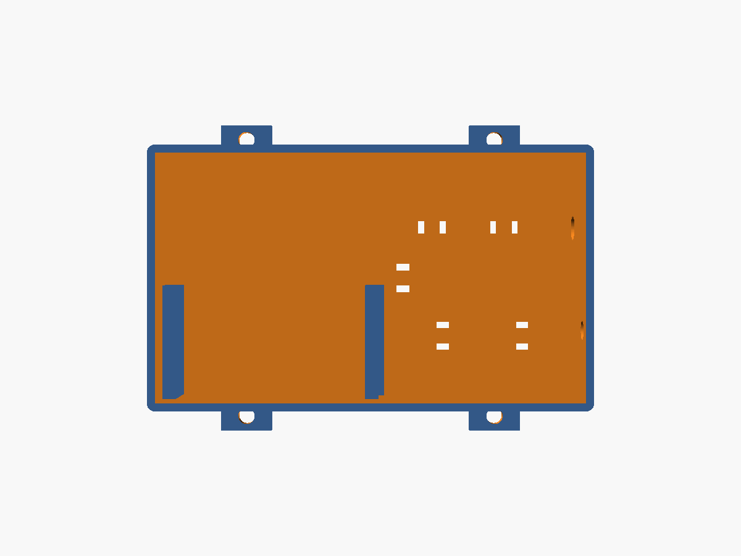
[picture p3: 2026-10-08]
gehaeuse/vorschau_tank_oben.png

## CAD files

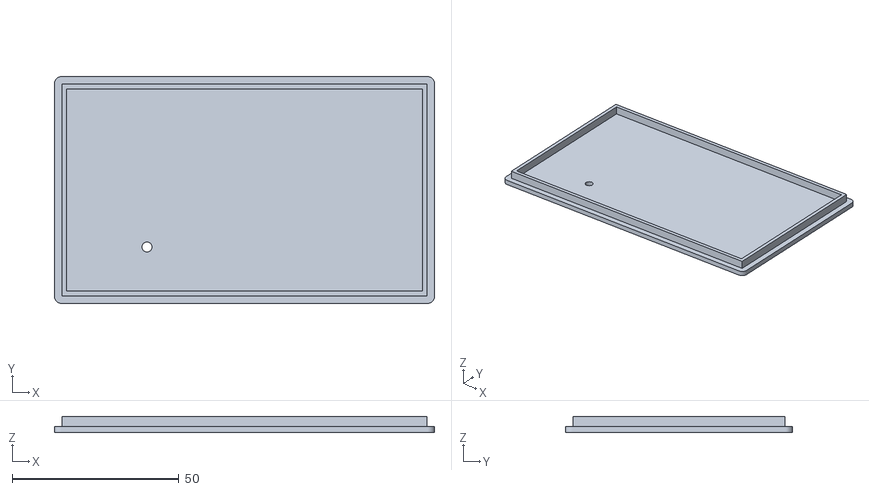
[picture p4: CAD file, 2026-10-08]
gehaeuse/tank_deckel.stl
114.0 x 68.0 x 4.80

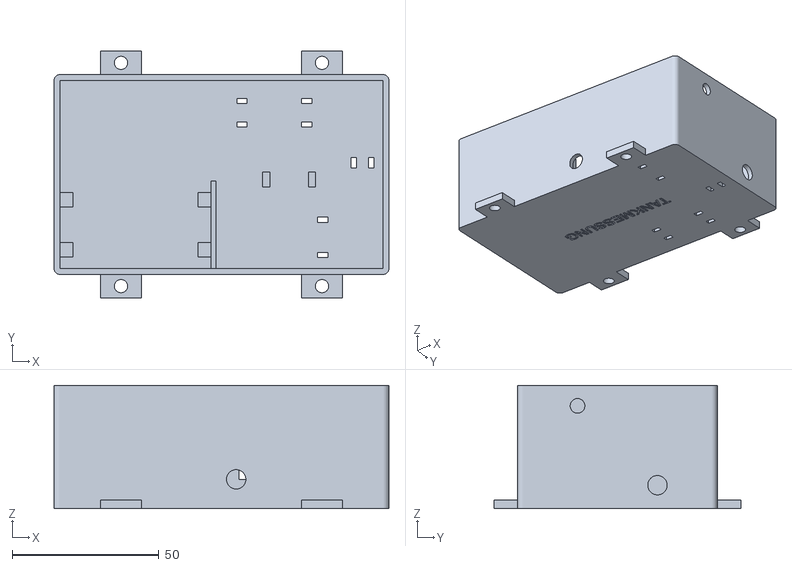
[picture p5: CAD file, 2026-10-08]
gehaeuse/tank_box.stl
114.0 x 84.0 x 42.0

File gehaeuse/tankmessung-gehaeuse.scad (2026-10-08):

// Gehaeuse „Tankmessung“ — pneumatische Oelstandsmessung an der Kupfer-Messleitung
// Inhalt: ESP32-DevKitC (der zweite aus der Bestellung), Drucksensor-Modul 0–40 kPa (HX710B),
//         Mini-Luftpumpe M20 (3 V), Dual-MOSFET-Modul CQUANZX (15 A, ohne Optokoppler; D4184-Modul taugt an 5 V nicht), Rueckschlagventil + T-Verbinder (Aquarium, 4 mm)
// Stand 04.10.2026 — Notiz project_oeltank_fuellstandsensor
//
// Die Masse von Pumpe, Sensor- und MOSFET-Modul sind nicht vermessen. Deshalb werden sie NICHT in
// passgenaue Aufnahmen gesetzt, sondern mit Kabelbindern auf Laschen im Boden gezogen (Schlitze 3,5 x 1,8 mm).
// Nur der ESP32 liegt wie im Heizungsgehaeuse auf Stirn-Auflagen.
//
// Teile: TEIL = "box" | "deckel" | "alle"
// Material: PETG oder PLA (Raumtemperatur, Wandmontage). 0,2 mm Schicht, keine Stuetzen.

TEIL = "alle";
$fn = 48;

// ---------- Innenmasse ----------
iL = 110;          // Laenge
iB = 64;           // Breite
iH = 40;           // Hoehe — 08.10.: 30 → 40, HX710B steht auf 17-mm-Stuetzen (Dupont darunter), Stutzen + Schlauchbogen oben drauf
w  = 2.0;          // Wand
bo = 2.0;          // Boden

// ESP32 (wie im Heizungsgehaeuse)
esp_l = 49.9; esp_b = 28.2; esp_spiel = 0.8;   // 48,24 + 1,6 USB-Ueberstand × 28,15 (Jens gemessen 06.10.)
auflage_h = 17;    // Platz fuer Dupont-Buchsen unter der Platine
auflage_t = 4.5;
usb_b = 12; usb_h = 7; usb_ueber_platte = 1.6;
stift_rand = 3.2;  // Stiftreihen 1,4 mm vom Laengsrand, Kunststoff + Dupont bis ~2,7 mm → Stuetzen bleiben 3,2 mm weg
mitte_frei = 12;   // freie Mitte zwischen den Stuetzen (USB-C-Loetlaschen)
hx_x = 80; hx_y0 = 25;   // HX710B: Mitte in x, Stiftleisten-Kante (vorn) in y
hx_b = 18.14; hx_st = 2.5;   // Breite ueber die Ohren, Stuetzenbreite
sma_x = 62;        // 08.10.: SMA rechts NEBEN dem ESP-Fach (Trennsteg endet bei x 55,1, Mutter ueber Ecken Ø9,2)

// Durchfuehrungen
schlauch_d = 6.6;  // 4-mm-Aquariumschlauch (6 mm aussen) zur Messleitung
kabel_d    = 5;    // optional: Leitung zum Optolink-ESP / Strom
// Kabelbinder-Laschen
kb_l = 3.5; kb_b = 1.8; kb_steg = 6;   // zwei Schlitze im Abstand kb_steg

aL = iL + 2*w; aB = iB + 2*w; aH = bo + iH;
esp_x0 = w;                         // ESP-Fach links (x = 0 … esp_l+2*spiel)
esp_iL = esp_l + 2*esp_spiel;
esp_iB = esp_b + 2*esp_spiel;

module rund_quader(l, b, h, r=2) {
    hull() for (x=[r, l-r], y=[r, b-r]) translate([x,y,0]) cylinder(r=r, h=h);
}

module kabelbinder_lasche(x, y, quer=false, steg=kb_steg) {
    // zwei Schlitze durch den Boden, Kabelbinder von unten durchziehen.
    // quer=false: Schlitze in x versetzt → Binderschlaufe umfasst ein Teil, das LAENGS y liegt.
    // quer=true:  Schlitze in y versetzt → Schlaufe umfasst ein Teil, das LAENGS x liegt.
    for (s=[-steg/2, steg/2])
        translate([x, y, -0.1]) rotate([0,0,quer?90:0])
            translate([s - kb_b/2, -kb_l/2, 0]) cube([kb_b, kb_l, bo+0.2]);
}

module box() {
    platte_z = bo + auflage_h;
    usb_z = platte_z + 1.6 + usb_ueber_platte;
    difference() {
        rund_quader(aL, aB, aH);
        translate([w, w, bo]) cube([iL, iB, iH+1]);

        // USB-C fuer den ESP32 (linke Stirnseite), ESP liegt an der vorderen Wand (y klein)
        translate([-1, w + esp_iB/2 - usb_b/2, usb_z - usb_h/2]) cube([w+2, usb_b, usb_h]);

        // SMA-Antennenbuchse (WROOM-32U braucht die externe Antenne) in der vorderen Wand, rechts neben dem
        // ESP-Fach. 08.10.: vorher unter der Platine bei x 39,5 / z 10 — die Mutter (bis z 14,6) traf dort die
        // Stifte der vorderen Leiste (Spitzen bis z ~10,5, y ~4). Pigtail reicht vom U.FL am Antennenende.
        translate([sma_x, -1, bo + 8]) rotate([-90,0,0]) cylinder(d=6.6, h=w+2);

        // Schlauch zur Messleitung (rechte Stirnseite, unten)
        translate([aL-w-1, aB*0.70, bo+6]) rotate([0,90,0]) cylinder(d=schlauch_d, h=w+2);
        // optionale Kabeldurchfuehrung (rechte Stirnseite, oben)
        translate([aL-w-1, aB*0.30, bo+iH-7]) rotate([0,90,0]) cylinder(d=kabel_d, h=w+2);

        // Lueftung hinten
        for (i=[0:7]) translate([w+40+i*7, aB-w-1, bo+8]) cube([2.4, w+2, 14]);

        // Kabelbinder-Laschen im rechten Bereich (Pumpe, Sensor, MOSFET)
        // 08.10. neu nach Jens' Massen (rechtes Fach innen x 55,1–112, y 2–66). Vorher lag die Pumpe quer zu
        // ihren Bindern und das MOSFET-Modul (35 mm) ragte 4 mm ueber die rechte Wand.
        // Pumpe Ø 9,95 × 38, Stutzen stirnseitig → laengs x, hinten, Stutzen nach rechts (Platz bis Ø 20)
        kabelbinder_lasche(64, 55, true, 8);   // Pumpe x 57–95 (Loetfahnen links, Stutzen ~+4 mm rechts)
        kabelbinder_lasche(86, 55, true, 8);
        // MOSFET CQUANZX 35 × 17,2 × 14,2 → laengs x, vorn rechts (x 74–109, y 4–21), weg von der SMA-Mutter
        kabelbinder_lasche(91.5, 12.6, true, 12);
        // Drucksensor-Modul HX710B: KEINE Binder — Stiftleiste zeigt nach unten (Fotos 08.10.), steht auf zwei Stuetzen (s. u.)
        // Rueckschlagventil / T-Verbinder → rechts, zwischen Pumpenstutzen und Schlauchausgang
        kabelbinder_lasche(105, 38, false, 6);

        // Wandlaschen-Loecher kommen ueber die Laschen (siehe unten)
        // Beschriftung Boden aussen
        translate([aL/2, aB/2, -0.01]) mirror([1,0,0]) linear_extrude(0.5)
            text("TANKMESSUNG", size=5, font="Liberation Sans:style=Bold", halign="center", valign="center");
    }
    // ESP32-Stuetzen: je Stirnseite zwei, ZWISCHEN Stiftleiste und Mitte (wie Optolink-Gehaeuse 07.10.).
    // 08.10.: vorher durchgehende Auflage ueber die ganze Breite → die nach unten zeigenden Stifte
    // (Leisten laufen ueber die ganze Platinenlaenge) waeren an beiden Enden aufgesessen.
    st_b = esp_b/2 - stift_rand - mitte_frei/2;      // Breite je Stuetze (~4,9 mm)
    for (x=[esp_x0, esp_x0 + esp_iL - auflage_t], s=[-1,1])
        translate([x, w + esp_iB/2 + (s>0 ? mitte_frei/2 : -mitte_frei/2 - st_b), bo])
            cube([auflage_t, st_b, auflage_h]);
    // HX710B-Stuetzen unter den beiden Befestigungsohren (Jens 08.10.: Ohrenbreite 18,14, Laenge 18,35, Koerper 13,59,
    // Hoehe ueber Platine bis Stutzen 11,24; Lochlinie ~7,3 mm von der Stiftleisten-Kante, aus Foto geschaetzt).
    // Stiftleiste (VCC OUT SCK GND) liegt 4,9–12,9 mm vom linken Ohrrand → Dupont-Buchsen haben ≥ 1 mm Luft zu den Stuetzen.
    // Befestigung: Heisskleber auf die Stuetzen (Lochabstand nur geschaetzt, daher keine Schraubloecher).
    for (x=[hx_x - hx_b/2, hx_x + hx_b/2 - hx_st])
        translate([x, hx_y0 + 7.3 - 2.5, bo]) cube([hx_st, 5, auflage_h]);
    // Trennsteg als Anschlag fuer die ESP-Platine (nur niedrig, laesst Kabel durch)
    translate([esp_x0 + esp_iL, w, bo]) cube([1.6, esp_iB, 6]);
    // Wandlaschen mit Schraubloch (oben und unten an den Laengsseiten)
    for (x=[aL*0.2, aL*0.8], y=[-8, aB]) translate([x-7, y, 0]) difference() {
        hull() { cube([14, 8, 3]); }
        translate([7, (y<0)?4:4, -1]) cylinder(d=4.5, h=5);
    }
}

module deckel() {
    difference() {
        union() {
            rund_quader(aL, aB, 1.8);
            translate([w+0.25, w+0.25, 1.8]) difference() {
                cube([iL-0.5, iB-0.5, 3]);
                translate([1.4,1.4,-1]) cube([iL-0.5-2.8, iB-0.5-2.8, 5]);
            }
        }
        // Sichtfenster ueber dem ESP fuer die Status-LED (optional)
        translate([w+esp_iL*0.5, w+esp_iB*0.5, -1]) cylinder(d=3, h=5);
    }
}

if (TEIL=="box") box();
if (TEIL=="deckel") deckel();
if (TEIL=="alle") { box(); translate([0, aB+20, 0]) deckel(); }

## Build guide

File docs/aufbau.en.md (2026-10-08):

🇩🇪 [Deutsche Version](aufbau.md)

# Assembly and commissioning (on the bench)

Basis: [`plaene/tank-bestueckung.pdf`](../plaene/tank-bestueckung.pdf) (top view 2:1) and
[`plaene/tankmessung-schaltplan.pdf`](../plaene/tankmessung-schaltplan.pdf). Pin assignment: [README, section 4](../README.en.md#4-pin-assignment-and-wiring).

## 1. Preparation

1. Print box and lid (`gehaeuse/tank_box.stl`, `tank_deckel.stl`; PETG or PLA, 0.2 mm, no supports).
2. Pump: solder the red and black wires to the solder tabs (red = +).
3. Have the flyback diode 1N5819 ready – it goes **into the OUT terminals** of the MOSFET module together with the wires, stripe (cathode) to OUT+.
4. Flash the firmware beforehand (see README, section 6) – once installed, the USB port is still reachable, but tight.

## 2. Assembly (order according to the assembly plan)

1. **Dupont cables first** onto the ESP32 and HX710B – later there is no room for fingers under the boards.
2. Place the **ESP32** on the 4 standoffs, USB-C on the left into the wall opening. Pigtail onto U.FL, SMA socket into the front wall to the right of the divider.
3. **HX710B** with hot glue onto its 2 standoffs, pin header to the **front**, hose barb pointing **up**.
4. **MOSFET module** front right with 1 cable tie, terminals towards the middle. Diode 1N5819: stripe to OUT+.
5. **Pump** at the back with 2 cable ties, ports to the right. Outlet port → check valve (arrow towards the T), leave the **inlet port open**.
6. **Check valve** on the right with 1 cable tie, aquarium T below it: one outlet to the HX710B barb (2.5 mm silicone), one through the right wall to the measuring line.
7. Tidy up the cables, push on the lid.

## 3. Commissioning

| Step | Expectation | If not |
|---|---|---|
| Plug in the USB power supply (≥ 1 A) | Device `Öltank` (oil tank) online in HA, `sensor.oltank_wlan_signal` (Wi-Fi signal) has a value | Fallback hotspot `Tank-Fallback` → captive portal |
| Wait ≥ 5 min | Sensor warm (zero point drifts ~0.5 mbar in the first minutes) | – |
| Hose end open, `button.oltank_messung_starten` (start measurement) | Pump audibly runs for 30 s, air blows out of the hose end; afterwards `sensor.oltank_druck` (pressure) ≈ 0 mbar | Fault pattern "pump does not run" in [fehlersuche.en.md](fehlersuche.en.md) |
| Hose end 10 cm into a glass of water | bubbles; pressure ≈ 9.8–10.5 mbar | see [einmessen.en.md](einmessen.en.md) |

> ⚠️ **Never pump with closed hose ends.** The pump manages 80–120 kPa, the sensor only tolerates 0–40 kPa.
> When testing, always have an open end or a water column it can bubble out into.

Result on 08.10.2026: function in the box ✔ (10.44/10.53 mbar at 10 cm water, 10 s settling, 3.5 min after switching on).

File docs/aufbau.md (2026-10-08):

🇬🇧 [English version](aufbau.en.md)

# Aufbau und Inbetriebnahme (am Tisch)

Grundlage: [`plaene/tank-bestueckung.pdf`](../plaene/tank-bestueckung.pdf) (Draufsicht 2:1) und
[`plaene/tankmessung-schaltplan.pdf`](../plaene/tankmessung-schaltplan.pdf). Pinbelegung: [README, Abschnitt 4](../README.md#4-pinbelegung-und-verdrahtung).

## 1. Vorbereiten

1. Box und Deckel drucken (`gehaeuse/tank_box.stl`, `tank_deckel.stl`; PETG oder PLA, 0,2 mm, ohne Stützen).
2. Pumpe: rote und schwarze Litze an die Lötfahnen löten (rot = +).
3. Freilaufdiode 1N5819 bereitlegen – sie kommt **mit in die OUT-Klemmen** des MOSFET-Moduls, Strich (Kathode) an OUT+.
4. Firmware vorher flashen (siehe README, Abschnitt 6) – im eingebauten Zustand ist der USB-Port zwar erreichbar, aber eng.

## 2. Bestücken (Reihenfolge laut Bestückungsplan)

1. **Dupont-Kabel zuerst** an ESP32 und HX710B stecken – unter den Platinen ist später kein Platz für Finger.
2. **ESP32** auf die 4 Stützen legen, USB-C links in die Wandöffnung. Pigtail an U.FL, SMA-Buchse in die vordere Wand rechts neben dem Trennsteg.
3. **HX710B** mit Heißkleber auf seine 2 Stützen, Stiftleiste nach **vorn**, Stutzen nach **oben**.
4. **MOSFET-Modul** vorn rechts mit 1 Kabelbinder, Klemmen zur Mitte. Diode 1N5819: Strich an OUT+.
5. **Pumpe** hinten mit 2 Kabelbindern, Stutzen nach rechts. Blasender Stutzen → Rückschlagventil (Pfeil zum T), **Ansaugstutzen offen** lassen.
6. **Rückschlagventil** rechts mit 1 Kabelbinder, darunter das Aquarium-T: ein Abgang zum HX710B-Stutzen (2,5-mm-Silikon), einer durch die rechte Wand zur Messleitung.
7. Kabel aufräumen, Deckel aufstecken.

## 3. Inbetriebnahme

| Schritt | Erwartung | Wenn nicht |
|---|---|---|
| USB-Netzteil (≥ 1 A) anstecken | Gerät „Öltank“ in HA online, `sensor.oltank_wlan_signal` hat einen Wert | Fallback-Hotspot `Tank-Fallback` → Captive Portal |
| ≥ 5 min warten | Sensor warm (Nullpunkt driftet in den ersten Minuten ~0,5 mbar) | – |
| Schlauchende offen, `button.oltank_messung_starten` | Pumpe läuft 30 s hörbar, am Schlauchende bläst es; danach `sensor.oltank_druck` ≈ 0 mbar | Fehlerbild „Pumpe läuft nicht“ in [fehlersuche.md](fehlersuche.md) |
| Schlauchende 10 cm in ein Wasserglas | perlt; Druck ≈ 9,8–10,5 mbar | siehe [einmessen.md](einmessen.md) |

> ⚠️ **Nie mit geschlossenen Schlauchenden pumpen.** Die Pumpe schafft 80–120 kPa, der Sensor verträgt nur 0–40 kPa.
> Beim Testen immer ein offenes Ende oder eine Wassersäule, in die es ausperlen kann.

Ergebnis am 08.10.2026: in der Box Funktion ✔ (10,44/10,53 mbar bei 10 cm Wasser, 10 s Ruhe, 3,5 min nach dem Einschalten).

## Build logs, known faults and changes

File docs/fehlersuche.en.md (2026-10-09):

🇩🇪 [Deutsche Version](fehlersuche.md)

# Troubleshooting

Known fault patterns from the project history (04.–09.10.2026).

| Fault pattern | Cause | Solution | confirmed? |
|---|---|---|---|
| Pump does not run, only ~0.86 V at the module output (VIN 4.77 V) | probably a **terminal contact** on the MOSFET module | Re-insert wires and diode into the terminals, tighten; afterwards it ran at 70 % | Cause **not** confirmed (08.10. 15:21–15:33) |
| MOSFET module does not switch at 5 V / only half | **D4184 module with PC817 optocoupler**: gate is supplied from the load voltage via 2 × 4.7 kΩ → gate = 50 % of the supply, only switches from ~6 V; PC817 too slow for 20 kHz; no flyback diode | Dual MOSFET module **without** optocoupler (CQUANZX B07VRCXGFY) + 1N5819 | confirmed (datasheet analysis + reviews, 06.10.) |
| Pressure does not build up / value too low, falling | **Leak at the branch to the old gauge**: check valve used as a plug leaks from ~10 mbar | Seal the branch firmly; leak test with 60 s settling time | confirmed (08.10., held shut → bubbles, value correct) |
| One-off drop in the leak test (10.44 → 6.65/6.47 mbar after 60 s) | unexplained – presumably push-fit connections settled after assembly | Repeat the run; two subsequent runs were tight | **not** confirmed |
| Zero point drifts in the first minutes (~38,500 raw ≈ 0.55 mbar ≈ 7 mm oil) | Sensor warming up (suspected) | wait ≥ 5 min before calibrating | Drift measured, cause suspected |
| `binary_sensor.oltank_uberdruck_abbruch` on / pressure > overpressure limit | Measuring line blocked; pump pushes against a closed line | the firmware switches the pump off itself (since 09.10.; sensor only 0–40 kPa, pump 80–120 kPa); have the line blown clear | Limit from calculation; cut-off **never triggered yet** |
| Pressure drops clearly after the pump stops (09.10.: 30.9 → 21.4 mbar in 10 s) | **Leak at the new connections** (T, silicone hose, clamps, branch to the old gauge) | reseal; leak test with 60 s – afterwards 1.3 mbar in 60 s | confirmed (09.10.) |
| ~1 mbar drop right after the pump stops, then almost nothing | not a leak: flow component (extra pressure the flowing air needs) | none | confirmed (09.10.) |
| Contents clearly below the delivered quantity | Measuring line ends **above the tank bottom** – oil below it is invisible to the measurement | set `number.oltank_leitungsende_uber_boden` (see [einmessen.en.md](einmessen.en.md)) | confirmed via delivery balance (09.10.) |
| Pumping against closed hose ends | Operator error while testing | never pump without an open end / water column | Rule |
| Cross-check shows somewhat above 9.81 mbar (e.g. 10.0–10.8) | Immersion depth by hand inaccurate (+1 mm ≈ +0.1 mbar) | none – tolerance of the method | confirmed |
| Flashing aborts with "No more data to read" | this board does not handle 460800 baud | `esptool … --baud 115200` with `firmware.factory.bin` | confirmed (06.10.) |
| Fallback hotspot does not accept the password / API key wrong | Test build with dummy secrets flashed (on the sister device 06.10.) | only `esphome run` with real secrets; `esphome upload` does **not** recompile | confirmed |
| USB port locked after re-plugging (Linux) | `/dev/ttyUSB0` is recreated, the permission is gone | repeat `setfacl -m u:$USER:rw /dev/ttyUSB0` or use group `dialout` | confirmed |
| Values do not change | Sensor is only read during the measurement (`update_interval: never`), automatic mode off by default | press `Messung starten` ("Start measurement") or switch on automatic mode | Configuration |
| Old gauge was stuck at ~800 l with an empty tank | **Gauge defective:** ~800 l is its rest position without pressure (not sludge – the line was clear); when pumped it shows just under 1,900 l with ~1,500 l in the tank | stop using the old gauge; the box is the reference | confirmed (09.10.: ~800 l without pressure, line clear) |

## Check steps for implausible values

1. Look at `sensor.oltank_druck_rohwert` (pressure raw value): the two readings per measurement are normally ~100–300 apart.
2. Pull the hose off the box, `Messung starten` ("Start measurement") → pressure must be ~0 mbar (otherwise redo the zero point, see [einmessen.en.md](einmessen.en.md)).
3. Glass test with 10 cm of water → ~9.8–10.5 mbar.
4. Leak test with 60 s settling time.
5. Only then suspect the line to the tank.

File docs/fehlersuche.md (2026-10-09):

🇬🇧 [English version](fehlersuche.en.md)

# Fehlersuche

Bekannte Fehlerbilder aus dem Projektverlauf (04.–09.10.2026).

| Fehlerbild | Ursache | Lösung | belegt? |
|---|---|---|---|
| Pumpe läuft nicht, am Modul-Ausgang nur ~0,86 V (VIN 4,77 V) | vermutlich **Klemmkontakt** am MOSFET-Modul | Litzen und Diode neu in die Klemmen, nachziehen; danach lief sie bei 70 % | Ursache **nicht** belegt (08.10. 15:21–15:33) |
| MOSFET-Modul schaltet an 5 V nicht / nur halb | **D4184-Modul mit PC817-Optokoppler**: Gate wird aus der Lastspannung über 2 × 4,7 kΩ versorgt → Gate = 50 % der Versorgung, schaltet erst ab ~6 V; PC817 zu langsam für 20 kHz; keine Freilaufdiode | Dual-MOSFET-Modul **ohne** Optokoppler (CQUANZX B07VRCXGFY) + 1N5819 | belegt (Datenblatt-Analyse + Rezensionen, 06.10.) |
| Druck baut sich nicht auf / Wert zu niedrig, sinkt | **Leck am Abzweig zur alten Anzeige**: Rückschlagventil als Verschluss leckt ab ~10 mbar | Abzweig fest verschließen; Dichtprobe mit 60 s Beruhigungszeit | belegt (08.10., zugehalten → perlt, Wert stimmt) |
| Einmaliger Abfall in der Dichtprobe (10,44 → 6,65/6,47 mbar nach 60 s) | ungeklärt – vermutlich Steckverbindungen haben sich nach dem Einbau gesetzt | Lauf wiederholen; zwei Folgeläufe waren dicht | **nicht** belegt |
| Nullpunkt wandert in den ersten Minuten (~38.500 Rohwert ≈ 0,55 mbar ≈ 7 mm Öl) | Aufwärmen des Sensors (vermutet) | vor dem Einmessen ≥ 5 min warten | Drift gemessen, Ursache vermutet |
| `binary_sensor.oltank_uberdruck_abbruch` an / Druck > Überdruck-Grenze | Messleitung zu; Pumpe drückt gegen geschlossene Leitung | Firmware schaltet die Pumpe selbst ab (seit 09.10.; Sensor nur 0–40 kPa, Pumpe 80–120 kPa); Leitung freiblasen lassen | Grenzwert aus Rechnung; Abschaltung **noch nie ausgelöst** |
| Druck fällt nach Pumpenstopp deutlich (09.10.: 30,9 → 21,4 mbar in 10 s) | **Leck an den neuen Anschlüssen** (T, Silikonschlauch, Schellen, Abzweig zur alten Anzeige) | neu abdichten; Dichtprobe mit 60 s – danach 1,3 mbar in 60 s | belegt (09.10.) |
| ~1 mbar Abfall direkt nach Pumpenstopp, danach fast nichts | kein Leck: Strömungsanteil (Druck, den die strömende Luft zusätzlich braucht) | keine | belegt (09.10.) |
| Inhalt deutlich unter der gelieferten Menge | Messleitung endet **über dem Tankboden** – Öl darunter sieht die Messung nicht | `number.oltank_leitungsende_uber_boden` setzen (siehe [einmessen.md](einmessen.md#3-abgleich-am-tank-nach-dem-einbau)) | belegt per Lieferbilanz (09.10.) |
| Pumpe gegen geschlossene Schlauchenden | Bedienfehler beim Testen | nie ohne offenes Ende / Wassersäule pumpen | Regel |
| Gegenprobe zeigt etwas über 9,81 mbar (z. B. 10,0–10,8) | Eintauchtiefe von Hand ungenau (+1 mm ≈ +0,1 mbar) | keine – Toleranz des Verfahrens | belegt |
| Flash bricht ab mit „No more data to read“ | dieses Board verträgt 460800 Baud nicht | `esptool … --baud 115200` mit `firmware.factory.bin` | belegt (06.10.) |
| Fallback-Hotspot nimmt Passwort nicht an / API-Schlüssel falsch | Prüf-Build mit Dummy-Secrets geflasht (beim Schwestergerät 06.10.) | nur `esphome run` mit echten Secrets; `esphome upload` übersetzt **nicht** neu | belegt |
| USB-Port nach Umstecken gesperrt (Linux) | `/dev/ttyUSB0` wird neu angelegt, Freigabe ist weg | `setfacl -m u:$USER:rw /dev/ttyUSB0` wiederholen oder Gruppe `dialout` | belegt |
| Werte ändern sich nicht | Sensor wird nur in der Messung gelesen (`update_interval: never`), Automatik ab Werk aus | „Messung starten“ drücken bzw. Automatik einschalten | Konfiguration |
| Alte Anzeige stand bei leerem Tank fest auf ~800 l | **Manometer defekt:** ~800 l ist seine Ruhestellung ohne Druck (nicht Schlamm – die Leitung war frei); gepumpt zeigt es knapp 1.900 l bei ~1.500 l | alte Anzeige nicht mehr verwenden; die Box ist der Maßstab | belegt (09.10.: drucklos ~800 l, Leitung frei) |

## Prüfschritte bei unplausiblen Werten

1. `sensor.oltank_druck_rohwert` ansehen: Zwei Lesungen je Messung liegen normal ~100–300 auseinander.
2. Schlauch an der Box abziehen, „Messung starten“ → Druck muss ~0 mbar sein (sonst Nullpunkt neu, siehe [einmessen.md](einmessen.md)).
3. Glas-Test mit 10 cm Wasser → ~9,8–10,5 mbar.
4. Dichtprobe mit 60 s Beruhigungszeit.
5. Erst dann die Leitung zum Tank verdächtigen.

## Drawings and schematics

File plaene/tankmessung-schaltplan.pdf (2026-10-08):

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

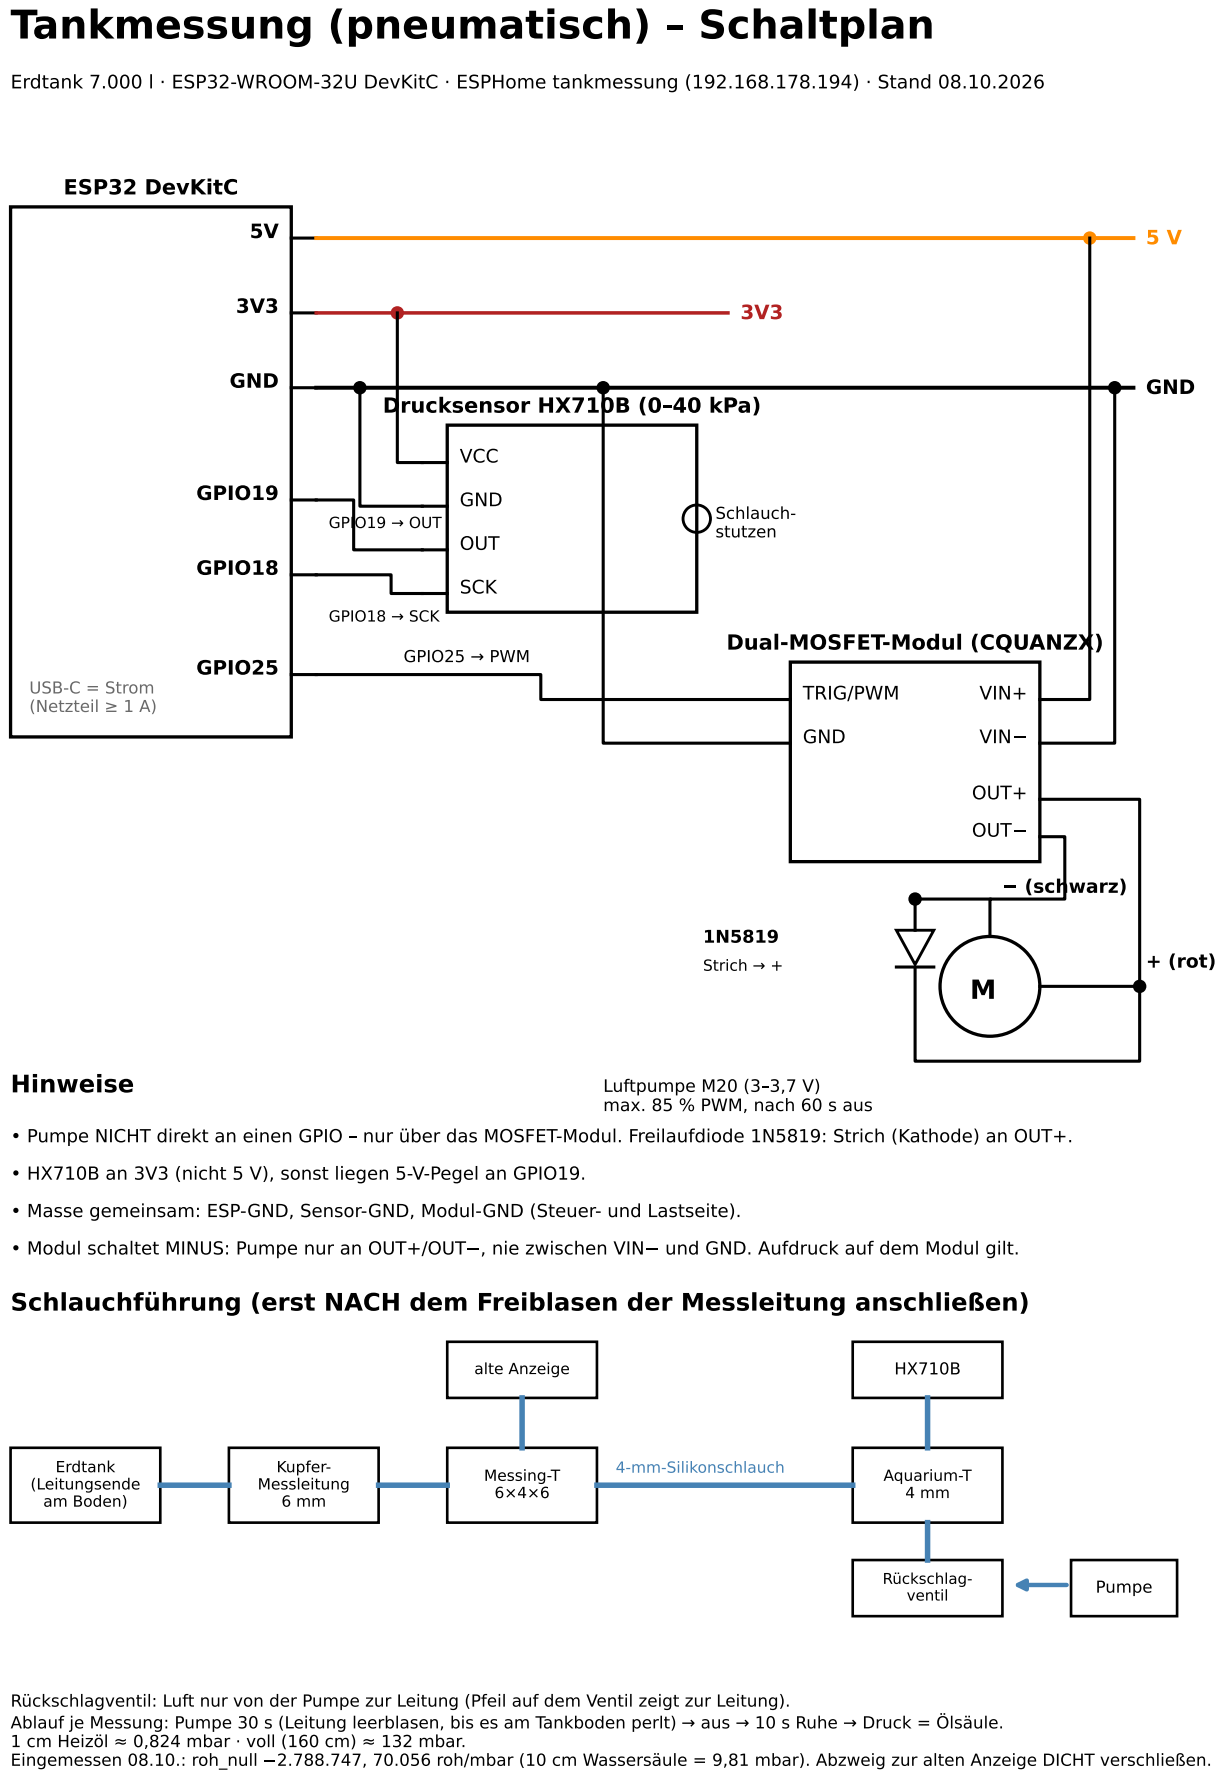
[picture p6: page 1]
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

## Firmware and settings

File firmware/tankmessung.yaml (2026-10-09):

# Oeltank (Erdtank 7.000 l, DIN 6608, Ø 1,6 m × 3,75 m) — pneumatische Fuellstandsmessung an der Kupfer-Messleitung
# Prinzip: Pumpe drueckt Luft in die Messleitung, bis sie am Tankboden ausperlt → Pumpe aus → der Restdruck in der
#   Leitung entspricht der Oelsaeule ueber dem Leitungsende (Heizoel ρ ≈ 0,84: 1 cm ≈ 0,824 mbar, voll ≈ 132 mbar).
# Hardware: ESP32-WROOM-32U DevKitC V4 (der zweite aus der Bestellung 04.10.)
#   Drucksensor-Modul 0–40 kPa (HX710B):  VCC → 3V3, GND → GND, OUT → GPIO19, SCK → GPIO18
#   Luftpumpe M20 (3–3,7 V) ueber Dual-MOSFET-Modul XY-MOS (CQUANZX):  TRIG/PWM → GPIO25, VIN 5 V, Pumpe an OUT+/OUT−, 1N5819 Strich an OUT+
#   Rueckschlagventil zwischen Pumpe und T-Stueck (Richtung: Pumpe → Leitung)
#   Abzweig zur alten Anzeige muss DICHT sein (ein Rueckschlagventil als Verschluss leckt, Test 08.10.)
# Bewusst KEINE automatische Messung ab Werk: erst nach dem Freiblasen der Messleitung und dem Einmessen
#   den Schalter „Automatische Messung“ einschalten. Die Pumpe laeuft nur ueber das Skript, mit fester Hoechstdauer.
# Einmessen: Nullpunkt (Schlauch offen, Sensor drucklos) → roh_null; dann bekannter Druck (z. B. Wassersaeule
#   10 cm = 9,81 mbar im Schlauch) → roh_pro_mbar. Danach per Peilstab/Liefermenge pruefen.
# Stand 09.10.2026 (Ueberdruck-Abschaltung, Leitungsende-Korrektur, Median aus 15 Werten) — Notiz project_oeltank_fuellstandsensor

substitutions:
  name: tankmessung
  friendly_name: Öltank
  # --- eingemessen 08.10.2026 16:18/16:21 am Tisch (Wassersaeule 10 cm), Sensor warm ---
  roh_null: "-2788747.0"     # HX710B-Rohwert bei 0 mbar (Nullpunkt-Drift beim Aufwaermen ~0,5 mbar in den ersten Minuten)
  roh_pro_mbar: "70056.0"    # Rohwert-Anstieg pro mbar: (−2101492 − −2788747) / 9,81
  oel_mbar_pro_cm: "0.824"  # Heizoel EL, ρ ≈ 0,84 kg/l
  tank_radius_dm: "8.0"
  tank_laenge_dm: "37.5"
  tank_nenn_l: "7000"

esphome:
  name: ${name}
  friendly_name: ${friendly_name}
  comment: Oeltank pneumatisch (HX710B + Pumpe)

esp32:
  board: esp32dev
  framework:
    type: esp-idf

logger:
  level: INFO

api:
  encryption:
    key: !secret tank_api_key

ota:
  - platform: esphome

wifi:
  ssid: !secret wifi_ssid
  password: !secret wifi_password
  ap:
    ssid: Tank-Fallback
    password: !secret tank_ap_password

captive_portal:

# ---------------- Pumpe ----------------
output:
  - platform: ledc
    id: pumpe_pwm
    pin: GPIO25
    frequency: 20000Hz
    max_power: 85%          # 08.10.: 70 % (≈3,3 V bei 4,77 V VIN) → 85 % ≈ 4,05 V (eigentliche Stoerung war ein Leck am Anzeige-Abzweig)

fan:
  - platform: speed
    id: pumpe
    output: pumpe_pwm
    name: Pumpe
    restore_mode: ALWAYS_OFF
    entity_category: diagnostic
    on_turn_on:
      - script.execute: pumpe_sicherung

number:
  - platform: template
    id: spuelzeit
    name: Spülzeit Pumpe
    unit_of_measurement: s
    min_value: 5
    max_value: 60
    step: 1
    initial_value: 30
    restore_value: true
    optimistic: true
    entity_category: config
  - platform: template
    id: beruhigungszeit
    name: Beruhigungszeit
    unit_of_measurement: s
    min_value: 2
    max_value: 60
    step: 1
    initial_value: 10
    restore_value: true
    optimistic: true
    entity_category: config
  # 09.10.: Ueberdruck-Abschaltung — der Druck wird WAEHREND des Pumpens alle 0,5 s gelesen. Freie Leitung: Druck steigt bis
  #   zur Oelsaeule (+ etwas Stroemungswiderstand) und bleibt dort; verstopft: steigt weiter → Pumpe aus, Messung verworfen.
  #   Sensor endet bei 400 mbar (0–40 kPa), die Pumpe schafft gegen eine geschlossene Leitung 800–1200 mbar.
  - platform: template
    id: ueberdruck_grenze
    name: Überdruck-Grenze
    unit_of_measurement: mbar
    min_value: 50
    max_value: 300
    step: 10
    initial_value: 150
    restore_value: true
    optimistic: true
    entity_category: config
  # 09.10.: Messleitung endet UEBER dem Tankboden (Lieferbilanz: gemessen 36,1 cm = 1.184 l < 1.500 l geliefert − ~35 l Verbrauch).
  #   Mindestwert 6,5 cm (Saugrohr 3 cm ueber Boden angenommen) = vorsichtig, Inhalt eher zu niedrig. Genau abgleichen bei der
  #   naechsten Lieferung (Messung direkt davor + danach, bekannte Liefermenge).
  - platform: template
    id: leitung_ueber_boden
    name: Leitungsende über Boden
    unit_of_measurement: cm
    min_value: 0
    max_value: 30
    step: 0.1
    initial_value: 6.5
    restore_value: true
    optimistic: true
    entity_category: config
    on_value:
      then:
        - if:
            condition:
              lambda: "return !id(pumpt) && !isnan(id(druck_mbar).state);"
            then:
              - component.update: fuellhoehe
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

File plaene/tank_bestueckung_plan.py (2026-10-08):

import matplotlib
matplotlib.use("Agg")
import matplotlib.pyplot as plt
from matplotlib.patches import Rectangle, FancyBboxPatch, Circle, FancyArrowPatch
from matplotlib.backends.backend_pdf import PdfPages

MM = 1/25.4
fig = plt.figure(figsize=(297*MM, 210*MM))
# Zeichenflaeche im Massstab 2:1 : 114 mm Gehaeuse -> 228 mm
ax = fig.add_axes([12/297, 58/210, 228/297, 136/210])
ax.set_xlim(-2, 116); ax.set_ylim(-2, 70); ax.set_aspect("equal"); ax.axis("off")

def box(x, y, w, h, fc, ec="black", lw=1, z=2, ls="-", alpha=1):
    ax.add_patch(Rectangle((x, y), w, h, fc=fc, ec=ec, lw=lw, zorder=z, ls=ls, alpha=alpha))
def txt(x, y, s, size=7, **k):
    ax.text(x, y, s, fontsize=size, ha=k.pop("ha", "center"), va=k.pop("va", "center"), zorder=10, **k)

# Gehaeuse (aussen 114 x 68, innen 2..112 x 2..66)
ax.add_patch(FancyBboxPatch((0, 0), 114, 68, boxstyle="round,pad=0,rounding_size=2", fc="#e8e8e8", ec="black", lw=1.5, zorder=0))
box(2, 2, 110, 64, "white", lw=0.6, z=1)
# Waende beschriften
txt(57, -1.2, "VORNE (Wand mit SMA-Buchse)", 6.5, style="italic")
txt(57, 69.2, "HINTEN (Lüftungsschlitze)", 6.5, style="italic")
for i in range(8): box(42+i*7, 66, 2.4, 2, "white", lw=0.4, z=1)

# ESP-Stuetzen + ESP
for x in (2, 49):
    for y in (16.9-10.9, 16.9+6):
        box(x, y, 4.5, 4.9, "#b07c3c", lw=0.4, z=2)
box(2.8, 2.8, 49.9, 28.2, "#2d6cdf", alpha=0.35, lw=1.2, z=3)
txt(27, 22, "ESP32 DevKitC", 9, weight="bold")
txt(27, 17, "liegt auf 4 Stützen (braun),\nStifte + Dupont-Stecker nach UNTEN", 6.5)
txt(27, 9.5, "USB-C ← links durch die Wand", 6.5)
box(-0.5, 16.9-3.5, 3, 7, "#2d6cdf", lw=0.8, z=4)  # USB-Oeffnung
txt(48, 27, "U.FL", 6, color="#123")
# Trennsteg
box(53.5, 2, 1.6, 29.8, "#888", lw=0.4, z=2)
txt(54.3, 34, "Trennsteg", 5.5, rotation=90, va="bottom")
# SMA
ax.add_patch(Circle((62, 1), 3.3, fc="#d4a017", ec="black", lw=0.8, zorder=4))
txt(62, 7.5, "SMA-\nBuchse", 6)
ax.plot([48, 52, 58, 62], [27, 30, 12, 4], color="#d4a017", lw=1.2, zorder=5, ls="--")
txt(56, 20, "Pigtail", 5.5, color="#8a6a00", rotation=-70)

# MOSFET XY-MOS 35 x 17,2 (x 74-109, y 4-21.2)
box(74, 4, 35, 17.2, "#1f5fa8", alpha=0.45, lw=1.2, z=3)
txt(91.5, 12.6, "MOSFET-Modul\nXY-MOS", 8, weight="bold")
box(74.5, 5, 5, 15, "#3aa0d0", lw=0.6, z=4); txt(77, 12.6, "Klemmen\nOUT/VIN", 5, rotation=90)
txt(106, 12.6, "TRIG\nGND", 5.5)
# Kabelbinder MOSFET
ax.plot([91.5, 91.5], [6.6-1.75, 18.6+1.75], color="red", lw=1.5, zorder=6, ls=":")

# HX710B auf Stuetzen (x 70.9-89.1, y 25-43.6)
for x in (70.93, 86.57): box(x, 29.8, 2.5, 5, "#b07c3c", lw=0.4, z=2)
box(70.9, 25, 18.2, 18.6, "#d9433b", alpha=0.45, lw=1.2, z=3)
txt(80, 33.5, "HX710B", 8.5, weight="bold")
txt(80, 27, "VCC OUT SCK GND\n(Stifte vorn, nach unten)", 5)
ax.add_patch(Circle((80, 39.5), 2.0, fc="black", zorder=5)); txt(80, 42.6, "Stutzen ↑", 5.5)
txt(80, 46, "Heißkleber auf die 2 Stützen", 5.5, color="#7a2a00")

# Pumpe (x 57-95, y 50-60) + Stutzen
box(57, 50, 38, 10, "#7f8c8d", alpha=0.6, lw=1.2, z=3)
txt(74, 55, "Pumpe (Lötfahnen links)", 8, weight="bold")
box(95, 51.5, 4, 2.5, "#555", lw=0.6, z=4); box(95, 56, 4, 2.5, "#555", lw=0.6, z=4)
txt(97, 49.5, "Stutzen →", 5.5)
for x in (64, 86): ax.plot([x, x], [51-1.75, 59+1.75], color="red", lw=1.5, zorder=6, ls=":")

# Rueckschlagventil + T (rechts)
box(102.5, 36, 5, 12, "#9b59b6", alpha=0.5, lw=1, z=3)
txt(105, 42, "Ventil", 5.5, rotation=90)
ax.annotate("", xy=(105, 36.5), xytext=(105, 47.5), arrowprops=dict(arrowstyle="-|>", color="#4a235a", lw=1.2), zorder=7)
ax.plot([105, 105], [38-3, 38+3], color="red", lw=1.5, zorder=6, ls=":")
box(103, 30.5, 4, 4, "#f39c12", lw=0.8, z=4); txt(110, 32.5, "T", 7, weight="bold")

# Schlaeuche
hose = dict(color="#16a085", lw=2.4, zorder=5, solid_capstyle="round")
ax.plot([99, 101.5, 105, 105], [57.2, 57.2, 54, 48], **hose)   # Pumpe (blasend) -> Ventil
ax.plot([105, 105], [36, 34.5], **hose)                        # Ventil -> T
ax.plot([103, 92, 80], [32.5, 38, 39.5], **hose)               # T -> HX710B
ax.plot([107, 109.5, 113.5], [32.5, 47.6, 47.6], **hose)       # T -> Schlauchausgang
ax.add_patch(Circle((113, 47.6), 1.8, fc="white", ec="#16a085", lw=1.5, zorder=6))
txt(116.5, 51.5, "Schlauch zur\nMessleitung\n(rechte Wand)", 6, ha="left")
ax.plot([99, 101], [52.7, 52.7], color="#16a085", lw=1, zorder=5, ls=":")
txt(104.5, 63, "2. Stutzen = Ansaugung, OFFEN lassen", 5.5)
ax.add_patch(Circle((113, 20.4), 1.3, fc="white", ec="black", lw=1, zorder=6))
txt(116.5, 20.4, "Kabeldurchführung\n(optional, oben)", 6, ha="left")

# Kabel (schematisch)
wire = dict(lw=1.1, zorder=4, alpha=0.9)
ax.plot([45, 66, 74.5], [31, 31, 14], color="#c0392b", **wire)       # 5V -> VIN+
ax.plot([45, 64, 74.5], [30, 29, 11], color="black", **wire)         # GND -> VIN-
ax.plot([50, 60, 70, 106], [31.5, 36, 23, 15], color="#e67e22", **wire)  # GPIO25 -> TRIG
ax.plot([57, 74.5], [55, 18], color="#c0392b", **wire, ls="--")     # Pumpe -> OUT
ax.plot([30, 40, 72], [31, 34, 26], color="#8e44ad", **wire)         # Sensor 4 Adern
txt(36, 36.5, "4 Adern zum HX710B\n3V3 · GPIO19 · GPIO18 · GND", 5.5, color="#5b2c6f")
txt(64, 23.5, "5V/GND → VIN", 5.5, color="#922")
txt(63.5, 41, "Pumpe → OUT+/OUT−\n(+ Diode in die Klemmen)", 5.5, color="#922")
txt(93, 26.5, "GPIO25 → TRIG", 5.5, color="#a04000")

# Titel
fig.text(12/297, 202/210, "Tankmessung – Bestückung der Box (Draufsicht, Deckel ab, Maßstab 2:1)", fontsize=13, weight="bold")
fig.text(12/297, 196.5/210, "tank_box.stl Stand 08.10.2026 · Innen 110 × 64 × 40 mm · rote Punktlinien = Kabelbinder durch die Bodenschlitze", fontsize=8)

# Legende / Schritte rechts unten und unten
schritte = (
"Einbau-Reihenfolge\n"
"1. Dupont-Kabel an ESP32 + HX710B stecken (vorher!) – unter den Platinen ist später kein Platz für Finger.\n"
"2. ESP32 auf die 4 Stützen legen, USB-C links in die Wandöffnung. Pigtail an U.FL, SMA-Buchse in die vordere Wand rechts neben dem Trennsteg.\n"
"3. HX710B mit Heißkleber auf seine 2 Stützen, Stiftleiste nach VORN, Stutzen zeigt nach oben.\n"
"4. MOSFET-Modul vorn rechts mit 1 Kabelbinder, Klemmen zur Mitte (links). Diode 1N5819: Strich an OUT+.\n"
"5. Pumpe hinten mit 2 Kabelbindern, Stutzen nach rechts. Blasender Stutzen → Ventil (Pfeil zum T), Ansaugstutzen offen.\n"
"6. Ventil rechts mit 1 Kabelbinder, darunter das T: ein Abgang zum HX710B-Stutzen, einer durch die rechte Wand zur Messleitung.\n"
"7. Kabel aufräumen, Deckel drauf. Prüfen: Messung starten → am Schlauchende perlt es / bläst es.")
fig.text(12/297, 50/210, schritte, fontsize=7.6, va="top", linespacing=1.45)
fig.text(250/297, 52/210,
"Farben\n■ blau  ESP32\n■ rot   HX710B\n■ dunkelblau  MOSFET\n■ grau  Pumpe\n■ lila  Rückschlagventil\n■ orange  T-Stück\n■ braun  Stützen\n━ grün  Schläuche\n┄ rot  Kabelbinder",
fontsize=7, va="top", linespacing=1.5)

out = "tank-bestueckung"
fig.savefig(out + ".png", dpi=130)
fig.savefig(out + ".pdf")

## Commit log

2026-10-08 Initial commit: firmware, plans, enclosures and documentation (DE/EN)
    [tank_box.stl, tank_deckel.stl, tankmessung-gehaeuse.scad]
2026-10-09 Überdruck-Abschaltung, Leitungsende-Korrektur, Einbau-Ergebnisse 09.10.
    Firmware (Stand ESPHome Builder 09.10.2026):
    - Druck wird während des Pumpens alle 0,5 s gelesen; über der
    einstellbaren Überdruck-Grenze (Standard 150 mbar) geht die Pumpe
    sofort aus und die Messung wird verworfen. Neue Entitäten
    Höchstdruck beim Pumpen und Überdruck-Abbruch.
    - Einstellbare Korrektur „Leitungsende über Boden“ (Standard 6,5 cm),
    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
2026-10-09 Firmware: Median aus 15 Messwerten, Messstreuung, Genauigkeitshinweise
    15 Einzelwerte nach der Beruhigungszeit, Median als Messwert, neuer Diagnosesensor
    Messstreuung. Doku DE/EN: Chip-Rauschen 0,04-0,07 mbar, Lauf-zu-Lauf bis ~18 l,
    Glaettung in HA ueber 4 Messungen; Box misst nach jedem Neustart sofort.
    Fixes #3
    [tankmessung.yaml]
